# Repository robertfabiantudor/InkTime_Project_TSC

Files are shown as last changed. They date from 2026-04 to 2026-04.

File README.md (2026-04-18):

# InkTime Smartwatch

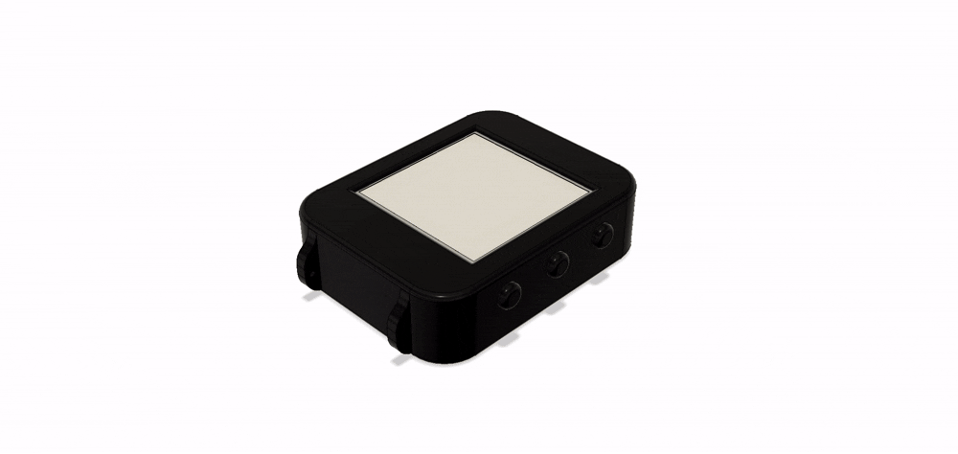
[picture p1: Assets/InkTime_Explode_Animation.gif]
InkTime_Explode_Animation


<br/>
<br/>

## Block Diagram
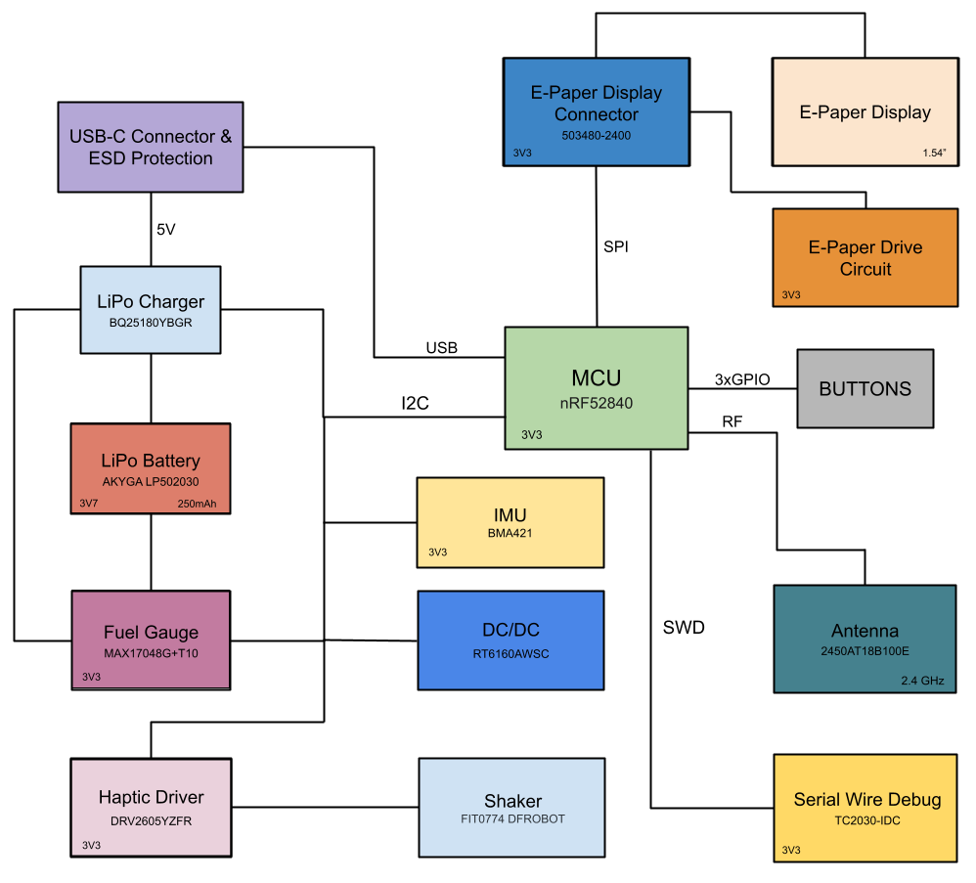
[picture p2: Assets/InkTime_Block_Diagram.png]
InkTime Block Diagram


<br/>
<br/>

## Bill of Materials(BOM)

| Name | Component Type | Part Number | Qty | JLCPCB Part Link | Datasheet Link|
|---|---|---|-----|---|---|
| ANT1 | Antenna | 2450AT18B100E | 1 | [View Part](https://jlcpcb.com/partdetail/JohansonDielectrics-2450AT18B100E/C2917717) | [View Datasheet](https://www.lcsc.com/datasheet/C2917717.pdf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) |
| C1, C2, C17, C18 | Capacitor | GRM0335C1H120JA01D | 4 | [View Part](https://jlcpcb.com/partdetail/MurataElectronics-GRM0335C1H120JA01D/C85890) | [View Datasheet](https://www.lcsc.com/datasheet/C85890.pdf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) |
| C1-EP-DR, C24, C39 | Capacitor | GRM155R60J106ME44D | 3 | [View Part](https://jlcpcb.com/partdetail/MurataElectronics-GRM155R60J106ME44D/C76991) | [View Datasheet](https://www.lcsc.com/datasheet/C76991.pdf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) |
| C2-EP-DR | Capacitor | RVT1E4R7M0405 | 1 | [View Part](https://jlcpcb.com/partdetail/DMBJ-RVT1E4R7M0405_4_7UF25V/C970600) | [View Datasheet](https://www.lcsc.com/datasheet/C2895731.pdf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) |
| C3, C4 | Capacitor | GRM0335C1H1R0BA01D | 2 | [View Part](https://jlcpcb.com/partdetail/MurataElectronics-GRM0335C1H1R0BA01D/C85893) | [View Datasheet](https://www.lcsc.com/datasheet/C85893.pdf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) |
| C5, C7, C8, C12, C19 | Capacitor | GRM033R60J104KE19D | 5 | [View Part](https://jlcpcb.com/partdetail/MurataElectronics-GRM033R60J104KE19D/C76928) | [View Datasheet](https://www.lcsc.com/datasheet/C76928.pdf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) |
| C6, C14, C20, C21, C43 | Capacitor | GRM155R60J475KE96D | 5 | [View Part](https://jlcpcb.com/partdetail/MurataElectronics-GRM155R60J475KE96D/C76995) | [View Datasheet](https://www.lcsc.com/datasheet/C76995.pdf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) |
| C9 | Capacitor | GRM033R71E821KA01D | 1 | [View Part](https://jlcpcb.com/partdetail/197002-GRM033R71E821KA01D/C185597) | [View Datasheet](https://www.lcsc.com/datasheet/C185597.pdf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) |
| C11 | Capacitor | GRM0335C1E101JA01D | 1 | [View Part](https://jlcpcb.com/partdetail/MurataElectronics-GRM0335C1E101JA01D/C76917) | [View Datasheet](https://www.lcsc.com/datasheet/C76917.pdf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) |
| C15 | Capacitor | GRM155R60J105KE19D | 1 | [View Part](https://jlcpcb.com/partdetail/MurataElectronics-GRM155R60J105KE19D/C15684) | [View Datasheet](https://www.lcsc.com/product-detail/C15684.html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) |
| C16, C10, C13, C22 | Capacitor | GRM033R60J473KE19D | 4 | [View Part](https://jlcpcb.com/parts/componentSearch?searchTxt=GRM033R60J473KE19D) | [View Datasheet](https://www.lcsc.com/product-detail/C85925.html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) |
| C25, C33 | Capacitor | GRM155R60J226ME11D | 2 | [View Part](https://jlcpcb.com/partdetail/408393-GRM155R60J226ME11D/C415703) | [View Datasheet](https://www.lcsc.com/datasheet/C415703.pdf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) |
| C23, C27, C29, C30, C31, C32, C34, C37, C38, C42| Capacitor | GRM011R60J152KE01L | 10 | [View Part](https://jlcpcb.com/partdetail/22429554-GRM011R60J152KE01L/C21012218) | [View Datasheet](https://www.lcsc.com/datasheet/C21012218.pdf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) |
| D2, D4, D5  | Schottky Diode | MBR0530 | 3 | [View Part](https://jlcpcb.com/partdetail/onsemi-MBR0530/C232832) | [View Datasheet](https://www.lcsc.com/datasheet/C232832.pdf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) |
| D3 | ESD Protection | USBLC6-2SC6Y | 1 | [View Part](https://jlcpcb.com/partdetail/STMicroelectronics-USBLC62SC6Y/C2969755) | [View Datasheet](https://www.lcsc.com/datasheet/C2969755.pdf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) |
| EPD_C1, EPD_C2, EPD_C6–EPD_C12 | Capacitor | 0201WMJ0100TCE | 9 | [View Part](https://jlcpcb.com/partdetail/25795-0201WMJ0100TCE/C25052) | [View Datasheet](https://www.lcsc.com/datasheet/C25052.pdf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) |
| EPD_C5 | Capacitor | 500R07W104KV4T | 1 | [View Part](https://jlcpcb.com/partdetail/6103901-500R07W104KV4T_0_1uF50v/C5337557) | [View Datasheet](https://www.mouser.com/catalog/specsheets/johanson_joha-s-a0008490164-1.pdf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) |
| IC1 | LiPo Charger | BQ25180YBGR | 1 | [View Part](https://jlcpcb.com/partdetail/TexasInstruments-BQ25180YBGR/C3682423) | [View Datasheet](https://www.ti.com/cn/lit/gpn/bq25180) |
| IC2 | Haptic Driver | DRV2605YZFR | 1 | [View Part](https://jlcpcb.com/partdetail/TexasInstruments-DRV2605YZFR/C81079) | [View Datasheet](https://www.lcsc.com/datasheet/C81079.pdf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) |
| IC3 | IMU | BMA421 | 1 | [View Part](https://jlcpcb.com/partdetail/BoschSensortec-BMA421/C5242966) | [View Datasheet](https://files.pine64.org/doc/datasheet/pinetime/BST-BMA421-FL000.pdf) |
| IC9 | DC/DC Converter | RT6160AWSC | 1 | [View Part](https://jlcpcb.com/partdetail/RichtekTech-RT6160AWSC/C7065276) | [View Datasheet](https://www.lcsc.com/datasheet/C7065276.pdf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) |
| J1 | FPC Connector | 503480-2400 | 1 | [View Part](https://jlcpcb.com/partdetail/MOLEX-5034802400/C122434) | [View Datasheet](https://www.lcsc.com/datasheet/C122434.pdf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) |
| J2 | Debug Connector | TC2030-IDC | 1 | - | [View Datasheet](https://www.tag-connect.com/wp-content/uploads/bsk-pdf-manager/2019/12/TC2030-IDC-Datasheet-Rev-B.pdf) |
| J4 | USB-C Connector | KH-TYPE-C-16P | 1 | [View Part](https://jlcpcb.com/partdetail/Shenzhen_KinghelmElec-KH_TYPE_C16P/C709357) | [View Datasheet](https://www.lcsc.com/datasheet/C709357.pdf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) |
| L1 | Inductor | LQG15HS3N9S02D | 1 | [View Part](https://jlcpcb.com/partdetail/MurataElectronics-LQG15HS3N9S02D/C77109) | [View Datasheet](https://www.lcsc.com/datasheet/C77109.pdf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) |
| L2 | Inductor | LQW15DN100M00D | 1 | [View Part](https://jlcpcb.com/partdetail/MurataElectronics-LQW15DN100M00D/C910650) | [View Datasheet](https://www.lcsc.com/datasheet/C910650.pdf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) |
| L3 | Inductor | LQG15HS15NJ02D| 1 | [View Part](https://jlcpcb.com/partdetail/MurataElectronics-LQG15HS15NJ02D/C86059) | [View Datasheet](https://www.lcsc.com/datasheet/C86059.pdf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) |
| L5 | Inductor | LQG15HS27NJ02D | 1 | [View Part](https://jlcpcb.com/partdetail/MurataElectronics-LQG15HS27NJ02D/C12669) | [View Datasheet](https://www.lcsc.com/datasheet/C12669.pdf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) |
| L7 | Inductor | LQW15CNR47K10D| 1 | [View Part](https://jlcpcb.com/partdetail/MurataElectronics-LQW15CNR47K10D/C913544) | [View Datasheet](https://www.lcsc.com/datasheet/C913544.pdf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) |
| Q1 | P-Channel MOSFET | DMG2305UX-7 | 1 | [View Part](https://jlcpcb.com/partdetail/DiodesIncorporated-DMG2305UX7/C150470) | [View Datasheet](https://www.lcsc.com/datasheet/C150470.pdf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) |
| Q3 | N-Channel MOSFET | SI1308EDL-T1-GE3 | 1 | [View Part](https://jlcpcb.com/partdetail/VishayIntertech-SI1308EDL_T1GE3/C469327) | [View Datasheet](https://www.lcsc.com/datasheet/C469327.pdf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) |
| R_PWR_EPD, R2_EP_DR, R9 | Resistor | CPF0201D10KC1 | 3 | [View Part](https://jlcpcb.com/partdetail/TEConnectivity-CPF0201D10KC1/C4187156) | [View Datasheet](https://www.lcsc.com/datasheet/C4187156.pdf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) |
| R_TYPE_SEL | Resistor | RC0201FR-072R2L | 1 | [View Part](https://jlcpcb.com/partdetail/YAGEO-RC0201FR072R2L/C138154) | [View Datasheet](https://www.lcsc.com/datasheet/C138154.pdf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) |
| R1_EP_DR | Resistor | 25121WF470LT4E | 1 | [View Part](https://jlcpcb.com/partdetail/21809-25121WF470LT4E/C21097) | [View Datasheet](https://www.lcsc.com/datasheet/C21097.pdf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) |
| R1_USB1, R2_USB | Resistor | RC0201JR-075K1L | 2 | [View Part](https://jlcpcb.com/partdetail/YAGEO-RC0201JR075K1L/C163490) | [View Datasheet](https://www.lcsc.com/datasheet/C163490.pdf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) |
| R2, R3, R4 | Resistor | RC0201FR-070RL | 3 | [View Part](https://jlcpcb.com/partdetail/YAGEO-RC0201FR070RL/C106227) | [View Datasheet](https://www.lcsc.com/datasheet/C106227.pdf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) |
| R5, R7, R8 | Resistor | RC0201FR-0710KL | 3 | [View Part](https://jlcpcb.com/partdetail/YAGEO-RC0201FR0710KL/C106225) | [View Datasheet](https://www.lcsc.com/product-detail/C106225.html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) |
| R17, R18 | Resistor | AC0201FR-073K3L | 2 | [View Part](https://jlcpcb.com/partdetail/YAGEO-AC0201FR073K3L/C226534) | [View Datasheet](https://www.lcsc.com/datasheet/C226534.pdf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) |
| SW_DN, SW_ENT, SW_UP | Button | EVP-AKE31A | 3 | [View Part](https://jlcpcb.com/partdetail/PANASONIC-EVPAKE31A/C569760) | [View Datasheet](https://www.lcsc.com/datasheet/C569760.pdf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) |
| U1 | MCU | NRF52840-QIAA-R | 1 | [View Part](https://jlcpcb.com/partdetail/NordicSemicon-NRF52840_QIAAR/C190794) | [View Datasheet](https://www.lcsc.com/datasheet/C190794.pdf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) |
| U3 | Fuel Gauge | MAX17048G+T10 | 1 | [View Part](https://jlcpcb.com/partdetail/2777647-MAX17048GT10/C2682616) | [View Datasheet](https://www.lcsc.com/datasheet/C2682616.pdf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) |
| X1 | Crystal | X201232768KJD2SI | 1 | [View Part](https://jlcpcb.com/partdetail/357115-X201232768KJD2SI/C383843) | [View Datasheet](https://www.lcsc.com/datasheet/C383843.pdf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) |
| X2 | Crystal | X322532MOB4SI | 1 | [View Part](https://jlcpcb.com/partdetail/YXC_CrystalOscillators-X322532MOB4SI/C9009) | [View Datasheet](https://www.lcsc.com/datasheet/C9009.pdf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) |

<br/>
<br/>

## Hardware Functionality
### Overview
The system is built around the **nRF52840 microcontroller**, which controls all peripherals and manages communication between them. The design is centered on low power consumption and efficient interaction between modules.

<br/>

### Power Management
- Power is supplied through the **USB-C connector**, protected by an **ESD protection circuit**.  
- The input voltage is managed by the **LiPo charger**, which charges the battery and provides power to the system.
- A **DC/DC converter** generates a stable voltage of **3.3V** used by all components, ensuring consistent operation regardless of battery level.
- The **Fuel Gauge** monitors battery status and provides charge information to the MCU.

<br/>

### Communication Interfaces
- **I2C Bus**
  - Used by: IMU, Fuel Gauge, Haptic Driver, LiPo Charger  
  - Provides communication over shared **SDA** and **SCL** lines  
  - Allows multiple low-speed peripherals to be connected on the same bus  
  - Operates at standard or fast mode speeds, sufficient for sensor data and status monitoring  

- **SPI Bus**
  - Used by: E-Paper Display  
  - Enables fast data transfer required for updating the display  
  - Uses dedicated lines for clock and data, allowing higher throughput compared to I2C  

- **USB**
  - Used for power input and battery charging  
  - Can also be used for firmware upload or data communication if needed  

- **SWD**
  - Used for programming and debugging  
  - Provides direct access to the microcontroller for firmware flashing and real-time debugging

<br/>

### Display
- The **E-Paper display** is connected via an FPC connector and controlled through the SPI interface.  
- A dedicated **E-Paper driver circuit** manages the display operation.
- E-paper technology only consumes power while refreshing the image, which makes it well suited for low-power applications. To take full advantage of this, the display is powered through a controlled power switch, allowing it to be completely turned off when not actively used. This approach significantly reduces overall power consumption and extends battery life, especially in scenarios where the display content does not need to be updated frequently.

<br/>

### Sensors and Feedback Systems
- **IMU**  
  - The IMU is an accelerometer that is used for motion detection and activity tracking. 
  - It detects movement, orientation, steps and it can generate interrupts so the microcontroller only wakes up when needed, improving power efficiency.

- **Haptic Driver & Shaker**  
  - The haptic driver controls a vibration motor that provides user feedback. 
  - It is configured through I2C and can trigger predefined vibration patterns for notifications.

<br/>

### User Inputs
- **Buttons**  
  - The buttons are connected to GPIO pins and are used to detect user actions. 
  - They can trigger interrupts, allowing the system to wake from low-power states and respond quickly.

<br/>

### Wireless Connectivity
- **Antenna**  
  - The antenna is connected to the microcontroller's RF pin and is used for Low Energy communication via Bluetooth.
  - It enables wireless data exchange with external devices such as smartphones.

<br/>

### Debug Interface
- **Serial Wire Debug (SWD)**  
  - The SWD interface is used for programming and debugging the system during development. 
  - It provides direct access to the microcontroller for firmware upload and troubleshooting.

<br/>
<br/>

## MCU Pin Assignment
| Pin Names | Purpose | Target Component |
|---|---|---|
| DEC1-DEC6, DEC3V3 | Decoupling pins for stable internal power | External Decoupling Capacitors|
| P0.00/XL1, P0.01/XL2 | Used to connect external 32.768 kHz Crystal Oscillator (X2) | X2 Crystal Oscillator |
| P0.26 | Unused | Not connected |
| P0.27 | Unused | Not connected |
| P0.04/AIN2 | Unused | Not connected |
| P0.05/AIN3 | Chip Select (CS) - Enables communication with the display controller | E-Paper Display |
| P0.06, P0.07 | SDA & SCL - Used as shared I2C communication lines for connected devices| IMU, Fuel Gauge, Haptic Driver, LiPo Charger |
| P0.08, P1.08 | Used to receive interrupt signals from the accelerometer | IMU |
| P1.09 | Unused | Not connected |
| P0.11 | PMIC Interrupt - Indicates charging or power events | LiPo Charger |
| P0.12 | Haptic Enable: Sends a signal to activate the vibration motor | Haptic Driver |
| VDD, VDDH | Supply power to the system | DC/DC Converter |
| DCCH | Unused | Not connected |
| VBUS | Detects when USB power is present | USB-C Connector |
| D-, D+ | Carry USB data signals for communication | USB-C Connector |
| P0.13, P0.14, P1.02  | Connected to physical buttons for user input | Buttons |
| P0.15, P0.16, P0.17  | Used to control the display by selecting data or commands, resetting it when needed and checking if it is busy during updates | E-Paper Display |
| P0.18/RESET | Hardware reset signal | Reset Circuit |
| P0.19 | Unused | Not connected |
| P0.20 | Unused | Not connected |
| P0.21 | Unused | Not connected |
| P0.22 | Unused | Not connected |
| P0.23 | Unused | Not connected |
| P0.24 | Unused | Not connected |
| P0.25 | Unused | Not connected |
| P1.00 | Used for Serial Wire Output to send debug and trace data during development | Debug Interface (SWO) |
| VSS, VSS_PAD, VSS_PA | Ground connections | Main Ground Plane |
| XC1, XC2 | Provide the main high-frequency clock for the system and radio | X1 Crystal Oscillator |
| ANT | Connects the RF signal to the antenna | Antenna |
| P0.10/NFC2 | Fuel Gauge Alert - Signals low battery | Fuel Gauge |
| P0.09/NFC1 | Unused | Not connected |
| P1.07 | Unused | Not connected |
| P1.06 | Unused | Not connected |
| P1.05 | Unused | Not connected |
| P1.04 | Unused | Not connected |
| P1.03 | Unused | Not connected |
| P1.01 | Controls the power to the e-paper display by turning it on or off to save battery | E-Paper Power Switch (Q1 MOSFET) |
| SWDIO, SWDCLK | Used for programming and debugging through the SWD interface | Debug Port |
| DCC | Output from internal voltage regulators | LC Filter Circuit |
| P0.31/AIN7 | Unused | Not connected |
| P0.30/AIN6 | Unused | Not connected |
| P0.29/AIN5 | Unused | Not connected |
| P0.28/AIN4 | Unused | Not connected |
| P0.02/AIN0 | SPI Clock (SCK) - Synchronizes data sent to the display | E-Paper Display |
| P0.03/AIN1 | SPI Data Line (MOSI) - Sends data to the display | E-Paper Display |
| P1.15 | Unused | Not connected |
| P1.14 | Unused | Not connected |
| P1.13 | Unused | Not connected |
| P1.12 | Unused | Not connected |
| P1.11 | Unused | Not connected |
| P1.10 | Unused | Not connected |

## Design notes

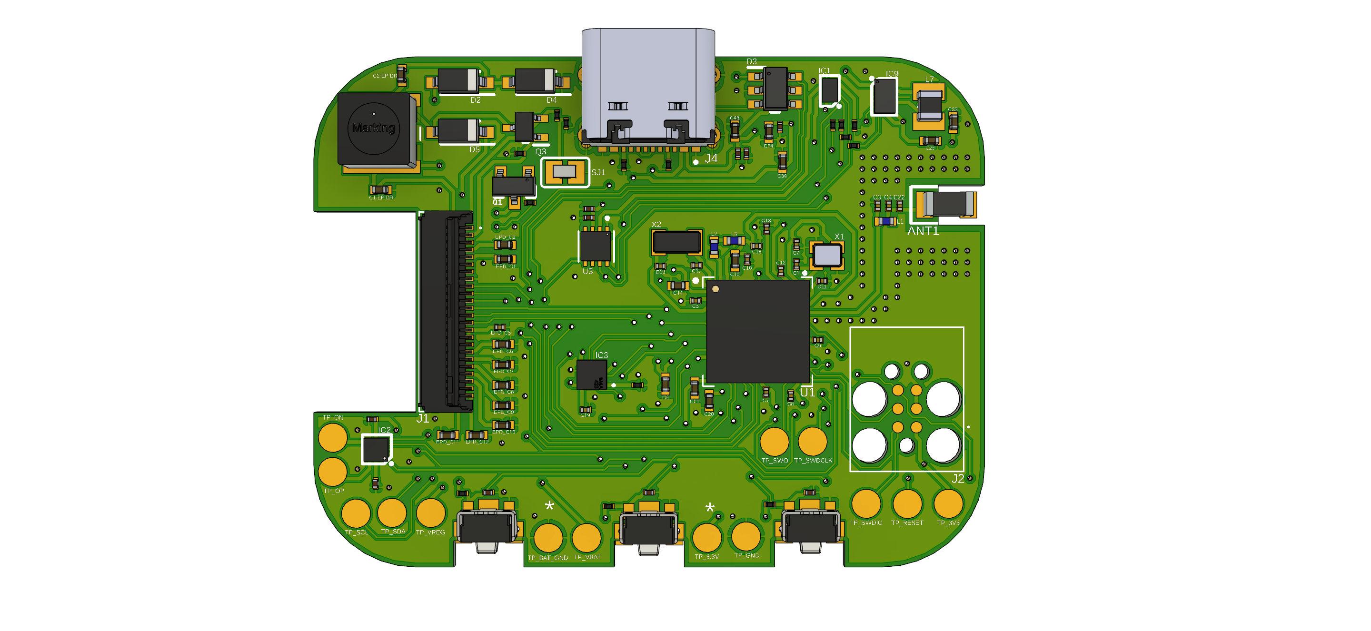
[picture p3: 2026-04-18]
Images/InkTime_3D_PCB_Front_View.png

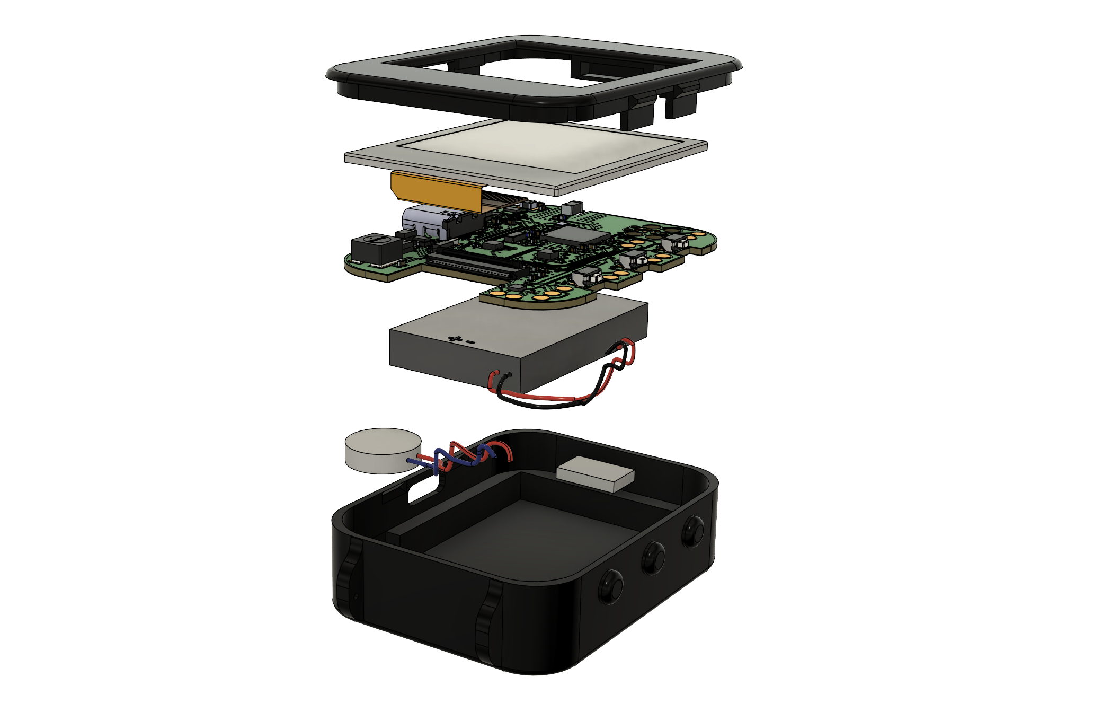
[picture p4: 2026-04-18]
Images/InkTime_Exploded_View.png

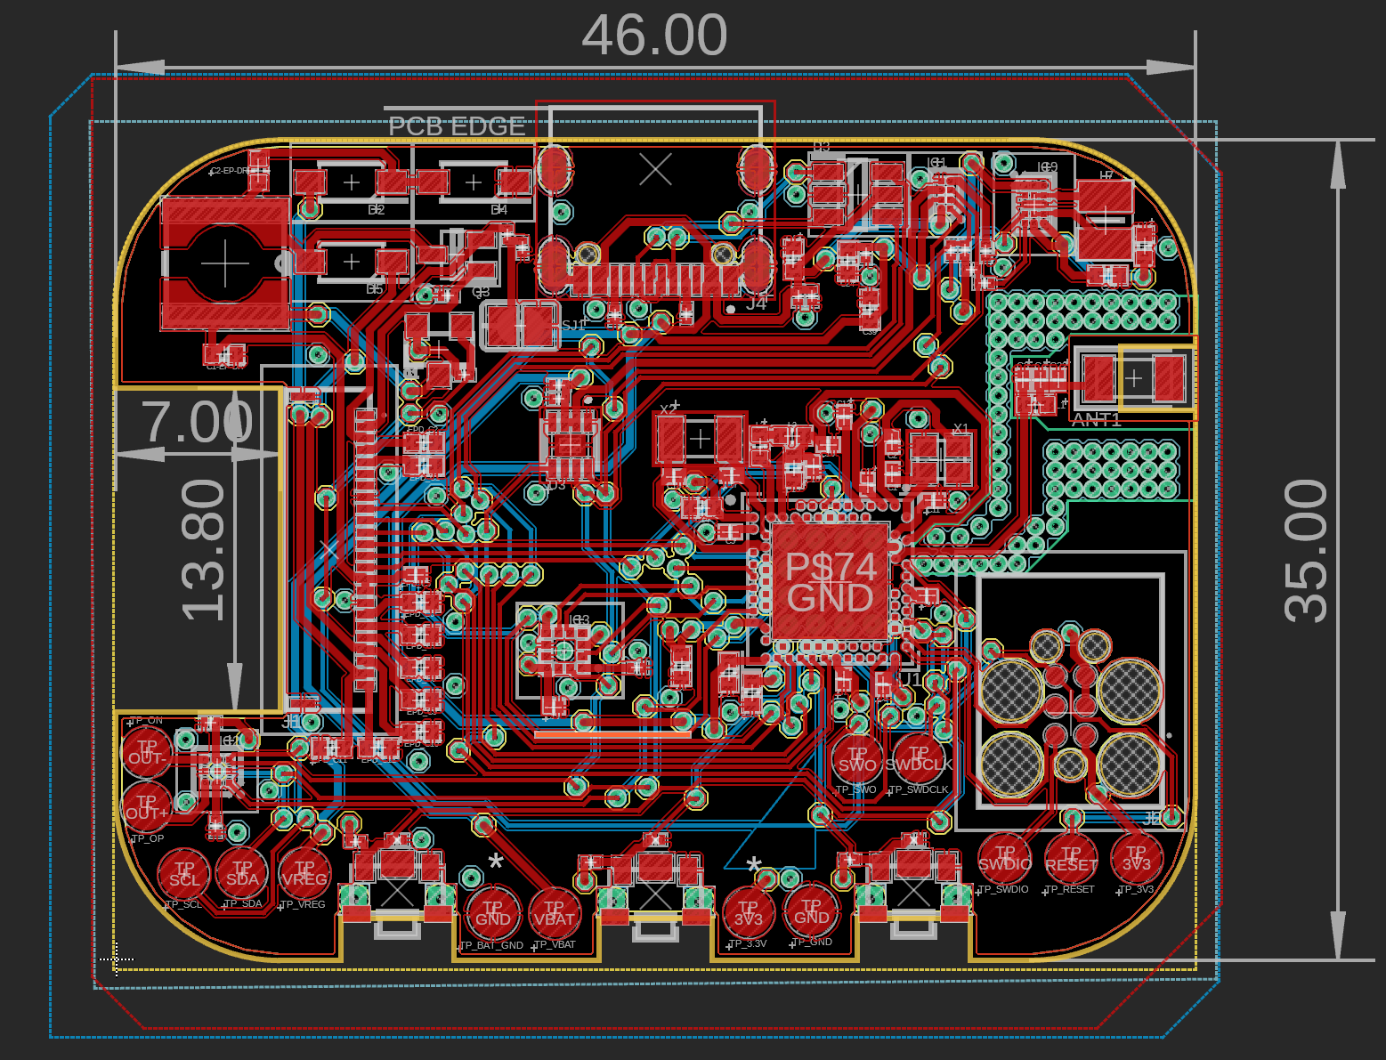
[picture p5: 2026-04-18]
Images/InkTime_2D_PCB.png

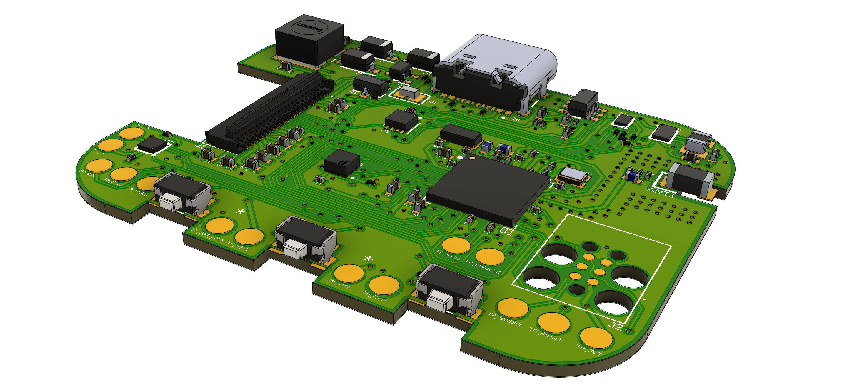
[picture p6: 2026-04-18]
Images/InkTime_3D_PCB_Angled_View.png

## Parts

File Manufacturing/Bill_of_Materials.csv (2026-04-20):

Qty | Value | Device | Package | Parts | Description | ARROW_PART_NUMBER | ARROW_PRICE-STOCK | AVAILABILITY | CHECK_PRICES | COPYRIGHT | DESCRIPTION | DIGI-KEY_PART_NUMBER_1 | DIGI-KEY_PART_NUMBER_2 | DIGI-KEY_PART_NUMBER_3 | HEIGHT | JLCPCB | MANUFACTURER_NAME | MANUFACTURER_PART_NUMBER | MF | MFR_NAME | MOUSER_PART_NUMBER | MOUSER_PRICE-STOCK | MP | PACKAGE | POPULARITY | PRICE | PROD_ID | PURCHASE-URL | SNAPEDA_LINK | TP_SIGNAL_NAME | VALUE
1 |  | ESP32_C6_LIBRARY_7_JUMPER_SJ | ESP32_C6_LIBRARY_7_JUMPER_SJ | SJ1 | SMD solder JUMPER |  |  |  |  |  |  |  |  |  |  |  |  |  |  |  |  |  |  |  | 3
3 | 0 | CPF0201D7K68C1_CPF0201D7K68C1 | CPF0201D7K68C1_0201 | R2, R3, R4 | 7.68k 0201 Thin Film Surface Mount Fixed Resistor +/-0.5% 0.031W CPF0201D7K68C1
4 | 0.1uF | GRM011R60J152KE01L_1_GRM011R60J152KE01L | GRM011R60J152KE01L_1_0201 | C23, C27, C34, C42 | Check availability
1 | 0.1uF/50V | NORDIC_NRF_3_CAPACITOR_0201_L | NORDIC_NRF_3_RESC0201_L | EPD_C5 | Generic chip capacitor
1 | 0.47 | CPF0201D7K68C1_CPF0201D7K68C1 | CPF0201D7K68C1_0201 | R1_EP_DR | 7.68k 0201 Thin Film Surface Mount Fixed Resistor +/-0.5% 0.031W CPF0201D7K68C1
1 | 1.0µF | NORDIC_NRF_3_CAPACITOR_0402_L | NORDIC_NRF_3_RESC0402_L | C15 | Generic chip capacitor
5 | 100nF | NORDIC_NRF_3_CAPACITOR_0201_L | NORDIC_NRF_3_RESC0201_L | C5, C7, C8, C12, C19 | Generic chip capacitor
1 | 100pF | NORDIC_NRF_3_CAPACITOR_0201_L | NORDIC_NRF_3_RESC0201_L | C11 | Generic chip capacitor
3 | 10K | CPF0201D7K68C1_CPF0201D7K68C1 | CPF0201D7K68C1_0201 | R2_EP_DR, R9, R_PWR_EPD | 7.68k 0201 Thin Film Surface Mount Fixed Resistor +/-0.5% 0.031W CPF0201D7K68C1
3 | 10k | CPF0201D7K68C1_CPF0201D7K68C1 | CPF0201D7K68C1_0201 | R5, R7, R8 | 7.68k 0201 Thin Film Surface Mount Fixed Resistor +/-0.5% 0.031W CPF0201D7K68C1
3 | 10uF | NORDIC_NRF_3_CAPACITOR_0402_L | NORDIC_NRF_3_RESC0402_L | C1-EP-DR, C24, C39 | Generic chip capacitor
1 | 10µH | NORDIC_NRF_2_INDUCTOR_0402_L | NORDIC_NRF_2_RESC0402_L | L2 | Generic chip inductor
4 | 12pF | NORDIC_NRF_3_CAPACITOR_0201_L | NORDIC_NRF_3_RESC0201_L | C1, C2, C17, C18 | Generic chip capacitor
1 | 15nH | NORDIC_NRF_2_INDUCTOR_0402_L | NORDIC_NRF_2_RESC0402_L | L3 | Generic chip inductor
2 | 1pF | NORDIC_NRF_3_CAPACITOR_0201_L | NORDIC_NRF_3_RESC0201_L | C3, C4 | Generic chip capacitor
6 | 1uF | GRM011R60J152KE01L_1_GRM011R60J152KE01L | GRM011R60J152KE01L_1_0201 | C29, C30, C31, C32, C37, C38 | Check availability
9 | 1uF/50V | NORDIC_NRF_3_CAPACITOR_0402_L | NORDIC_NRF_3_RESC0402_L | EPD_C1, EPD_C2, EPD_C6, EPD_C7, EPD_C8, EPD_C9, EPD_C10, EPD_C11, EPD_C12 | Generic chip capacitor
1 | 2.2 | CPF0201D7K68C1_CPF0201D7K68C1 | CPF0201D7K68C1_0201 | R_TYPE_SEL | 7.68k 0201 Thin Film Surface Mount Fixed Resistor +/-0.5% 0.031W CPF0201D7K68C1
3 | 2025-10-22_07-23-44_LIBRARY_EVP-AKE31ASW_EVP-AKE31A_PAN | 2025-10-22_07-23-44_LIBRARY_EVP-AKE31ASW_EVP-AKE31A_PAN | 2025-10-22_07-23-44_LIBRARY_SW_EVP-AKE31A_PAN | SW_DN, SW_ENT, SW_UP |  |  |  |  |  | Copyright (C) 2025 Ultra Librarian. All rights reserved. |  | P123437TR-ND | P123437CT-ND | P123437DKR-ND |  |  | Panasonic | EVP-AKE31A
1 | 20V/4.2A/52mO/1.4W | ESP32_C6_LIBRARY_4_ESP32_WROVER_SPARKFUN-DISCRETESEMI_MOSFET_PCH-DMG2305UX-7 | ESP32_C6_LIBRARY_4_ESP32_C6_LIBRARY_4_ESP32_C6_LIBRARY_4_ESP32_C6_LIBRARY_4_ESP32_WROVER_SPARKFUN-DISCRETESEMI_SOT23-3 | Q1 | P-channel MOSFETs |  |  |  |  |  |  |  |  |  |  |  |  |  |  |  |  |  |  |  |  |  | TRAN-14388 |  |  |  | 20V/4.2A/52mO/1.4W
2 | 22uF | NORDIC_NRF_3_CAPACITOR_0402_L | NORDIC_NRF_3_RESC0402_L | C25, C33 | Generic chip capacitor
1 | 2450AT18B100E | 2450AT18B100E_2450AT18B100E | 2450AT18B100E_ANTC3216X140N | ANT1 | Antennas 2.45GHz ANTENNA | 2450AT18B100E | https://www.arrow.com/en/products/2450at18b100e/johanson-dielectrics?utm_currency=USD&region=nac |  |  |  | Antennas 2.45GHz ANTENNA |  |  |  | 1.4mm |  | JOHANSON TECHNOLOGY | 2450AT18B100E |  |  | 609-2450AT18B100E | https://www.mouser.co.uk/ProductDetail/Johanson-Technology/2450AT18B100E?qs=yCnrNFeXz%252Bh5MFsFIXGZGA%3D%3D
1 | 3.9nH | NORDIC_NRF_2_INDUCTOR_0402_L | NORDIC_NRF_2_RESC0402_L | L1 | Generic chip inductor
1 | 32.768kHz | NORDIC_NRF_1_XTAL_32KHZ | NORDIC_NRF_1_XTAL_3215_N | X2
1 | 32MHz | NORDIC_NRF_XTAL_32MHZ | NORDIC_NRF_BT-XTAL_2016_N | X1
2 | 3K3 | CPF0201D7K68C1_CPF0201D7K68C1 | CPF0201D7K68C1_0201 | R17, R18 | 7.68k 0201 Thin Film Surface Mount Fixed Resistor +/-0.5% 0.031W CPF0201D7K68C1
1 | 4.7uF | NORDIC_NRF_3_CAPACITOR_0402_L | NORDIC_NRF_3_RESC0402_L | C43 | Generic chip capacitor
1 | 4.7uF/25V | NORDIC_NRF_3_CAPACITOR_0402_L | NORDIC_NRF_3_RESC0402_L | C2-EP-DR | Generic chip capacitor
4 | 4.7µF | NORDIC_NRF_3_CAPACITOR_0402_L | NORDIC_NRF_3_RESC0402_L | C6, C14, C20, C21 | Generic chip capacitor
1 | 47nF | NORDIC_NRF_3_CAPACITOR_0201_L | NORDIC_NRF_3_RESC0201_L | C16 | Generic chip capacitor
1 | 503480-2400 | 503480-2400_503480-2400 | 503480-2400_5034802400 | J1 | FFC & FPC Connectors 0.5mm FPC RA SMT Dual Contact 24Ckt |  |  |  |  |  | FFC & FPC Connectors 0.5mm FPC RA SMT Dual Contact 24Ckt |  |  |  | 1.87mm |  | Molex | 503480-2400 |  |  | 538-503480-2400 | https://www.mouser.co.uk/ProductDetail/Molex/503480-2400?qs=OAhjpuo3Vu7efIoxFh9AOw%3D%3D
2 | 5K1 | CPF0201D7K68C1_CPF0201D7K68C1 | CPF0201D7K68C1_0201 | R1_USB1, R2_USB | 7.68k 0201 Thin Film Surface Mount Fixed Resistor +/-0.5% 0.031W CPF0201D7K68C1
1 | 68uH | ESP32_C6_LIBRARY_2_744043680IND_4828-WE-TPC_WRE | ESP32_C6_LIBRARY_2_IND_4828-WE-TPC_WRE | L5 |  |  |  |  |  | Copyright (C) 2024 Ultra Librarian. All rights reserved. |  |  |  |  |  |  |  | 744043680 |  | Wurth Electronics
1 | 820pF | NORDIC_NRF_3_CAPACITOR_0201_L | NORDIC_NRF_3_RESC0201_L | C9 | Generic chip capacitor
1 | BMA421 | BMA423_BMA423 | BMA423_BMA423 | IC3 | Accelerometers Triaxial low-g 12bit Acceleration Sensor | BMA423 | https://www.arrow.com/en/products/bma423/bosch |  |  |  | Accelerometers Triaxial low-g 12bit Acceleration Sensor |  |  |  | 1mm |  | BOSCH | BMA423 |  |  | 262-BMA423 | https://www.mouser.co.uk/ProductDetail/Bosch-Sensortec/BMA423?qs=HXFqYaX1Q2xC%252BSgeGoX3mg%3D%3D
1 | BQ25180YBGR | BQ25180YBGR_BQ25180YBGR | BQ25180YBGR_BGA8C40P2X4_100X155X50 | IC1 | Charger IC Lithium Ion/Polymer, Lithium Iron Phosphate 8-DSBGA (1.6x1.1) | BQ25180YBGR | https://www.arrow.com/en/products/bq25180ybgr/texas-instruments?utm_currency=USD&region=nac |  |  |  | Charger IC Lithium Ion/Polymer | Lithium Iron Phosphate 8-DSBGA (1.6x1.1) |  |  |  | 0.5mm |  | Texas Instruments | BQ25180YBGR |  |  | 595-BQ25180YBGR | https://www.mouser.co.uk/ProductDetail/Texas-Instruments/BQ25180YBGR?qs=doiCPypUmgEWjAK%252BJAX6Tw%3D%3D
1 | DRV2605YZFR | DRV2605YZFR_DRV2605YZFR | DRV2605YZFR_BGA9C50P3X3_144X144X62 | IC2 | Haptic Driver for ERM/LRA with Built-In Library and Smart Loop Architecture | DRV2605YZFR | https://www.arrow.com/en/products/drv2605yzfr/texas-instruments?region=nac |  |  |  | Haptic Driver for ERM/LRA with Built-In Library and Smart Loop Architecture |  |  |  | 0.625mm |  | Texas Instruments | DRV2605YZFR
1 | FTC252012SR47MBCA | MLP2016SR47MT0S1_FTC252012SR47MBCA | MLP2016SR47MT0S1_INDC2016X100N | L7 | SMD / SMT Inductors (Coils), L=0.47?H, L x W x T : |  |  |  |  |  | SMD / SMT Inductors (Coils) | L=0.47?H | L x W x T : |  |  |  | 1mm | https://jlcpcb.com/partdetail/6763488-FTC252012SR47MBCA/C5832368 | TDK | FTC252012SR47MBCA
14 | HECTOR_WATCH_1_TPTP20R | HECTOR_WATCH_1_TPTP20R | HECTOR_WATCH_1_TP20R | TP_3.3V, TP_3V3, TP_BAT_GND, TP_GND, TP_ON, TP_OP, TP_RESET, TP_SCL, TP_SDA, TP_SWDCLK, TP_SWDIO, TP_SWO, TP_VBAT, TP_VREG | Test pad |  |  |  |  |  |  |  |  |  |  |  |  |  |  |  |  |  |  |  | 2
1 | KH-TYPE-C-16P | KH-TYPE-C-16P_KH-TYPE-C-16P | KH-TYPE-C-16P_KINGHELM_KH-TYPE-C-16P | J4 | Check availability |  |  | Not in stock | https://www.snapeda.com/parts/KH-TYPE-C-16P/Kinghelm/view-part/?ref=eda |  |  |  |  |  |  |  |  |  | kinghelm |  |  |  | KH-TYPE-C-16P | None |  | None |  |  | https://www.snapeda.com/parts/KH-TYPE-C-16P/Kinghelm/view-part/?ref=snap
1 | MAX17048G+T10 | ESP32_C6_LIBRARY_MAX17048G+T10 | ESP32_C6_LIBRARY_SON50P200X200X80-9N | U3 | Check availability |  |  | In Stock | https://www.snapeda.com/parts/MAX17048G+T10/Analog+Devices/view-part/?ref=eda |  | 3µA 1-Cell/2-Cell Fuel Gauge with ModelGauge |  |  |  |  |  |  |  | Analog Devices |  |  |  | MAX17048G+T10 | TDFN-8 Maxim |  | None |  | https://www.snapeda.com/api/url_track_click_mouser/?unipart_id=329239&manufacturer=Analog Devices&part_name=MAX17048G+T10&search_term=None | https://www.snapeda.com/parts/MAX17048G+T10/Analog+Devices/view-part/?ref=snap
3 | MBR0530 | ESP32_C6_LIBRARY_5_MBR0530 | ESP32_C6_LIBRARY_5_SOD3716X135N | D4, D5 | ON SEMICONDUCTOR - MBR0530 - DIODE, SCHOTTKY, 0.5A, 30V, SOD-123 |  |  | In Stock | https://www.snapeda.com/parts/MBR0530/Onsemi/view-part/?ref=eda |  | Diode Schottky 30 V 500mA Surface Mount SOD-123 |  |  |  |  |  |  |  | ON Semiconductor |  |  |  | MBR0530 | SOD-123-2 ON Semiconductor |  | None |  | https://www.snapeda.com/api/url_track_click_mouser/?unipart_id=179458&manufacturer=ON Semiconductor&part_name=MBR0530&search_term=None | https://www.snapeda.com/parts/MBR0530/Onsemi/view-part/?ref=snap
3 | N.C. | NORDIC_NRF_3_CAPACITOR_0201_L | NORDIC_NRF_3_RESC0201_L | C10, C13, C22 | Generic chip capacitor
1 | NRF52840_QF | NORDIC_NRF_4_NRF52840_QF | NORDIC_NRF_4_AQFN50P700X700X85_HS-74N | U1 | nRF52840
1 | RT6160AWSC | RT6160AWSC_RT6160AWSC | RT6160AWSC_BGA15C40P3X5_140X230X60 | IC9 | Buck-Boost Regulator Positive Output Step-Up/Step-Down I2C DC-DC Controller IC 15-WL-CSP (BSC) (1.4x2.3) |  |  |  |  |  | Buck-Boost Regulator Positive Output Step-Up/Step-Down I2C DC-DC Controller IC 15-WL-CSP (BSC) (1.4x2.3) |  |  |  | 0.6mm |  | RICHTEK | RT6160AWSC |  |  | 835-RT6160AWSC | https://www.mouser.co.uk/ProductDetail/Richtek/RT6160AWSC?qs=amGC7iS6iy%2FLd9PSoixZXQ%3D%3D
1 | SI1308EDL-T1-GE3 | ESP32_C6_LIBRARY_6_SI1308EDL-T1-GE3 | ESP32_C6_LIBRARY_6_SOT65P210X110-3N | Q3 | MOSFET N-Ch 30V 1.5A TrenchFET SC70 Vishay Si1308EDL-T1-GE3 N-channel MOSFET Transistor, 1.5 A, 30 V, 3-Pin SC-70 |  |  | In Stock | https://www.snapeda.com/parts/SI1308EDL-T1-GE3/Vishay+Siliconix/view-part/?ref=eda |  | Si1308EDL-T1-GE3 N-channel MOSFET Transistor | 1.5 A | 30 V | 3-Pin SC-70 | Siliconix / Vishay SI1308EDL-T1-GE3 |  |  |  |  |  |  |  | Vishay Siliconix |  |  |  | SI1308EDL-T1-GE3 | SOT-323 Vishay Semiconductor |  | None |  | https://www.snapeda.com/api/url_track_click_mouser/?unipart_id=274603&manufacturer=Vishay Siliconix&part_name=SI1308EDL-T1-GE3&search_term=None
1 | TC2030-IDC_TC2030-IDC | TC2030-IDC_TC2030-IDC | TC2030-IDC_TC2030IDC | J2 | CABLE ADAPTER 6 POS |  |  |  |  |  | CABLE ADAPTER 6 POS |  |  |  | 19mm |  | Tag Connect | TC2030-IDC
1 | USBLC6-2SC6Y | ESP32_C6_LIBRARY_3_USBLC6-2SC6Y | ESP32_C6_LIBRARY_3_SOT95P280X145-6N | D3 | Low Cap. ESD Protection Auto SOT-23-6 STMicroelectronics USBLC6-2SC6Y, Dual Uni-Directional TVS Diode Array, 6-Pin SOT-23 |  |  | In Stock | https://www.snapeda.com/parts/USBLC6-2SC6Y/STMicroelectronics/view-part/?ref=eda |  | 17V Clamp 5A (8/20µs) Ipp Tvs Diode Surface Mount SOT-23-6 |  |  |  |  |  |  |  | STMicroelectronics |  |  |  | USBLC6-2SC6Y | SOT-23-6 STMicroelectronics |  | None |  |  | https://www.snapeda.com/parts/USBLC6-2SC6Y/STMicroelectronics/view-part/?ref=snap

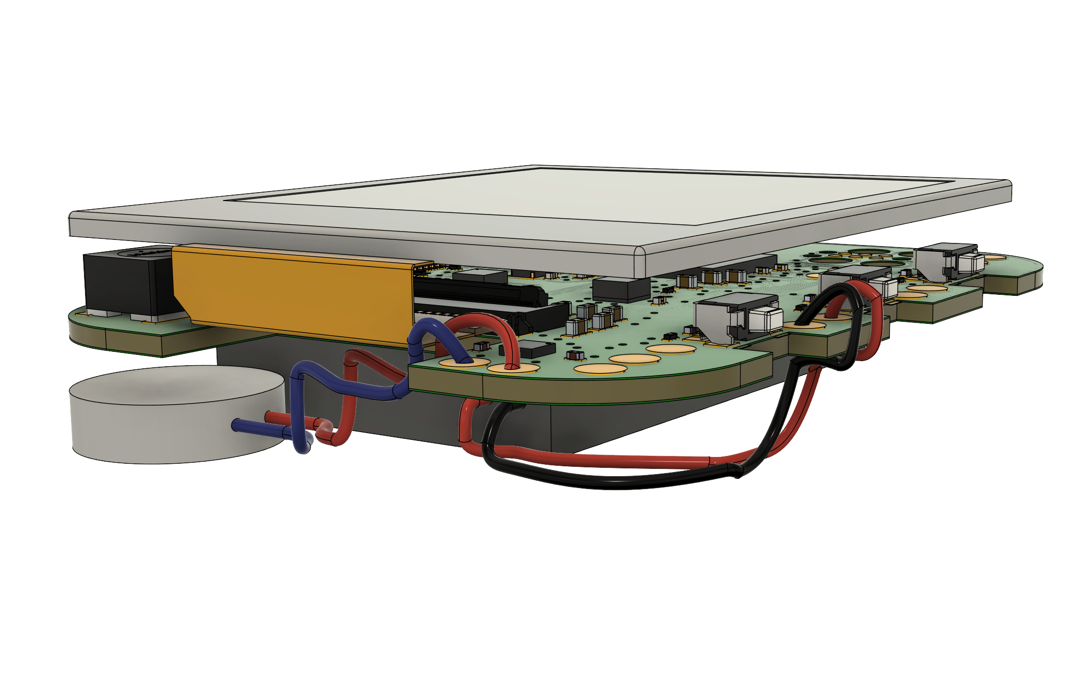
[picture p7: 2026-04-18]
Images/InkTime_Board_With_Custom_Components.png

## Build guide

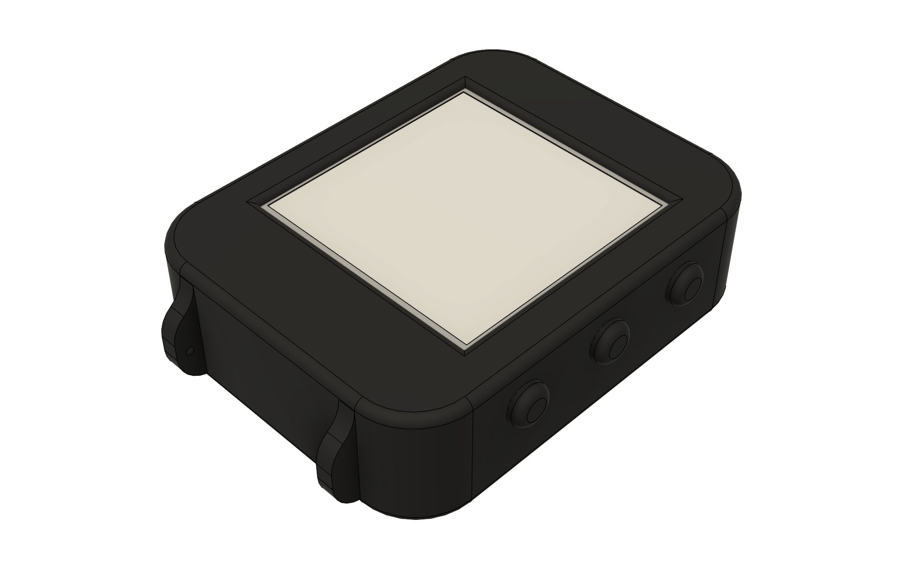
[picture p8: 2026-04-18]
Images/InkTime_Assembled.png

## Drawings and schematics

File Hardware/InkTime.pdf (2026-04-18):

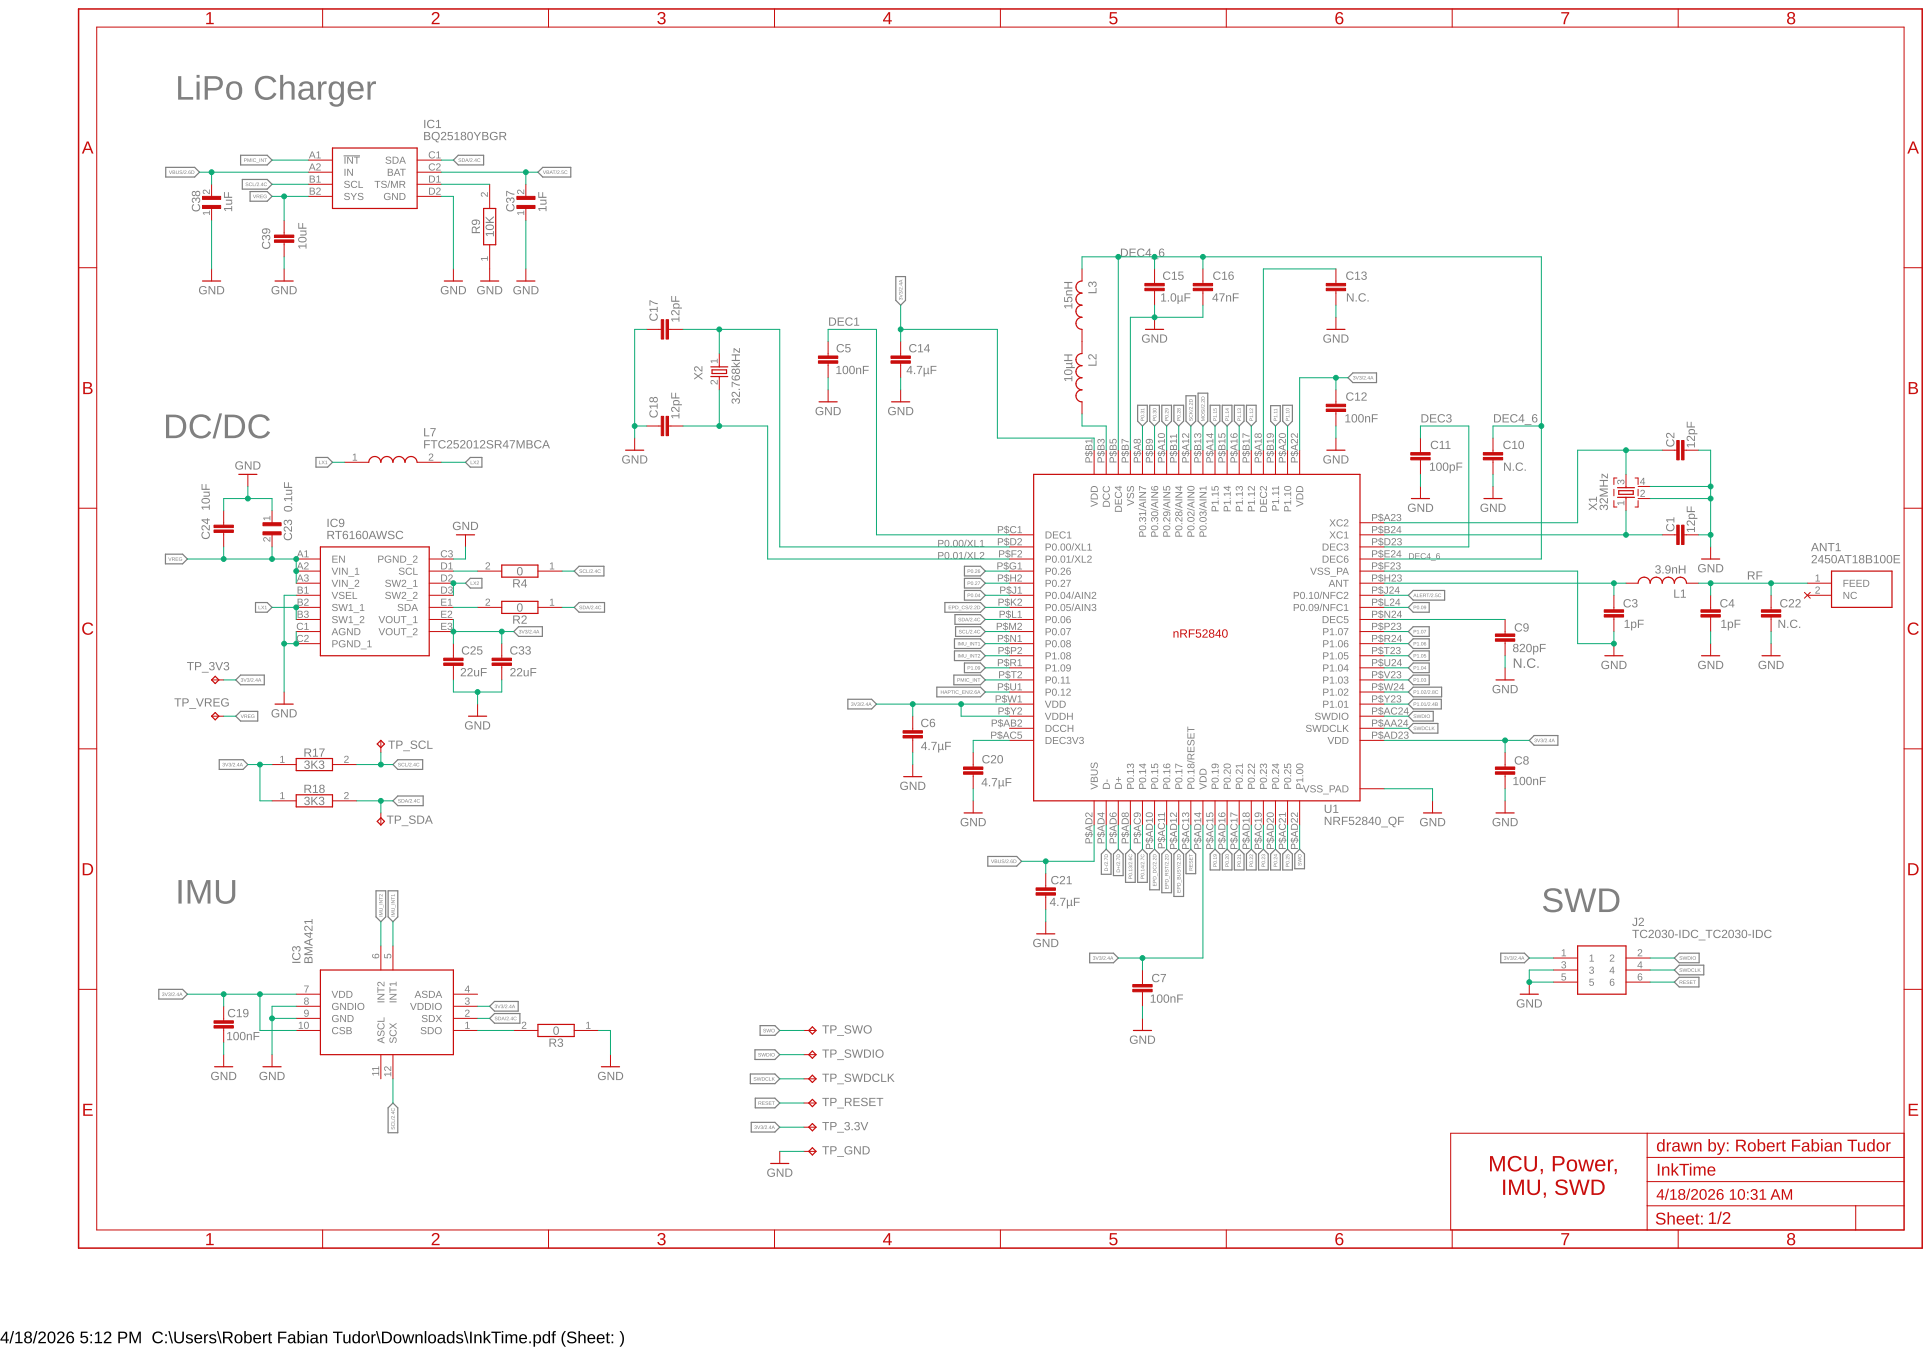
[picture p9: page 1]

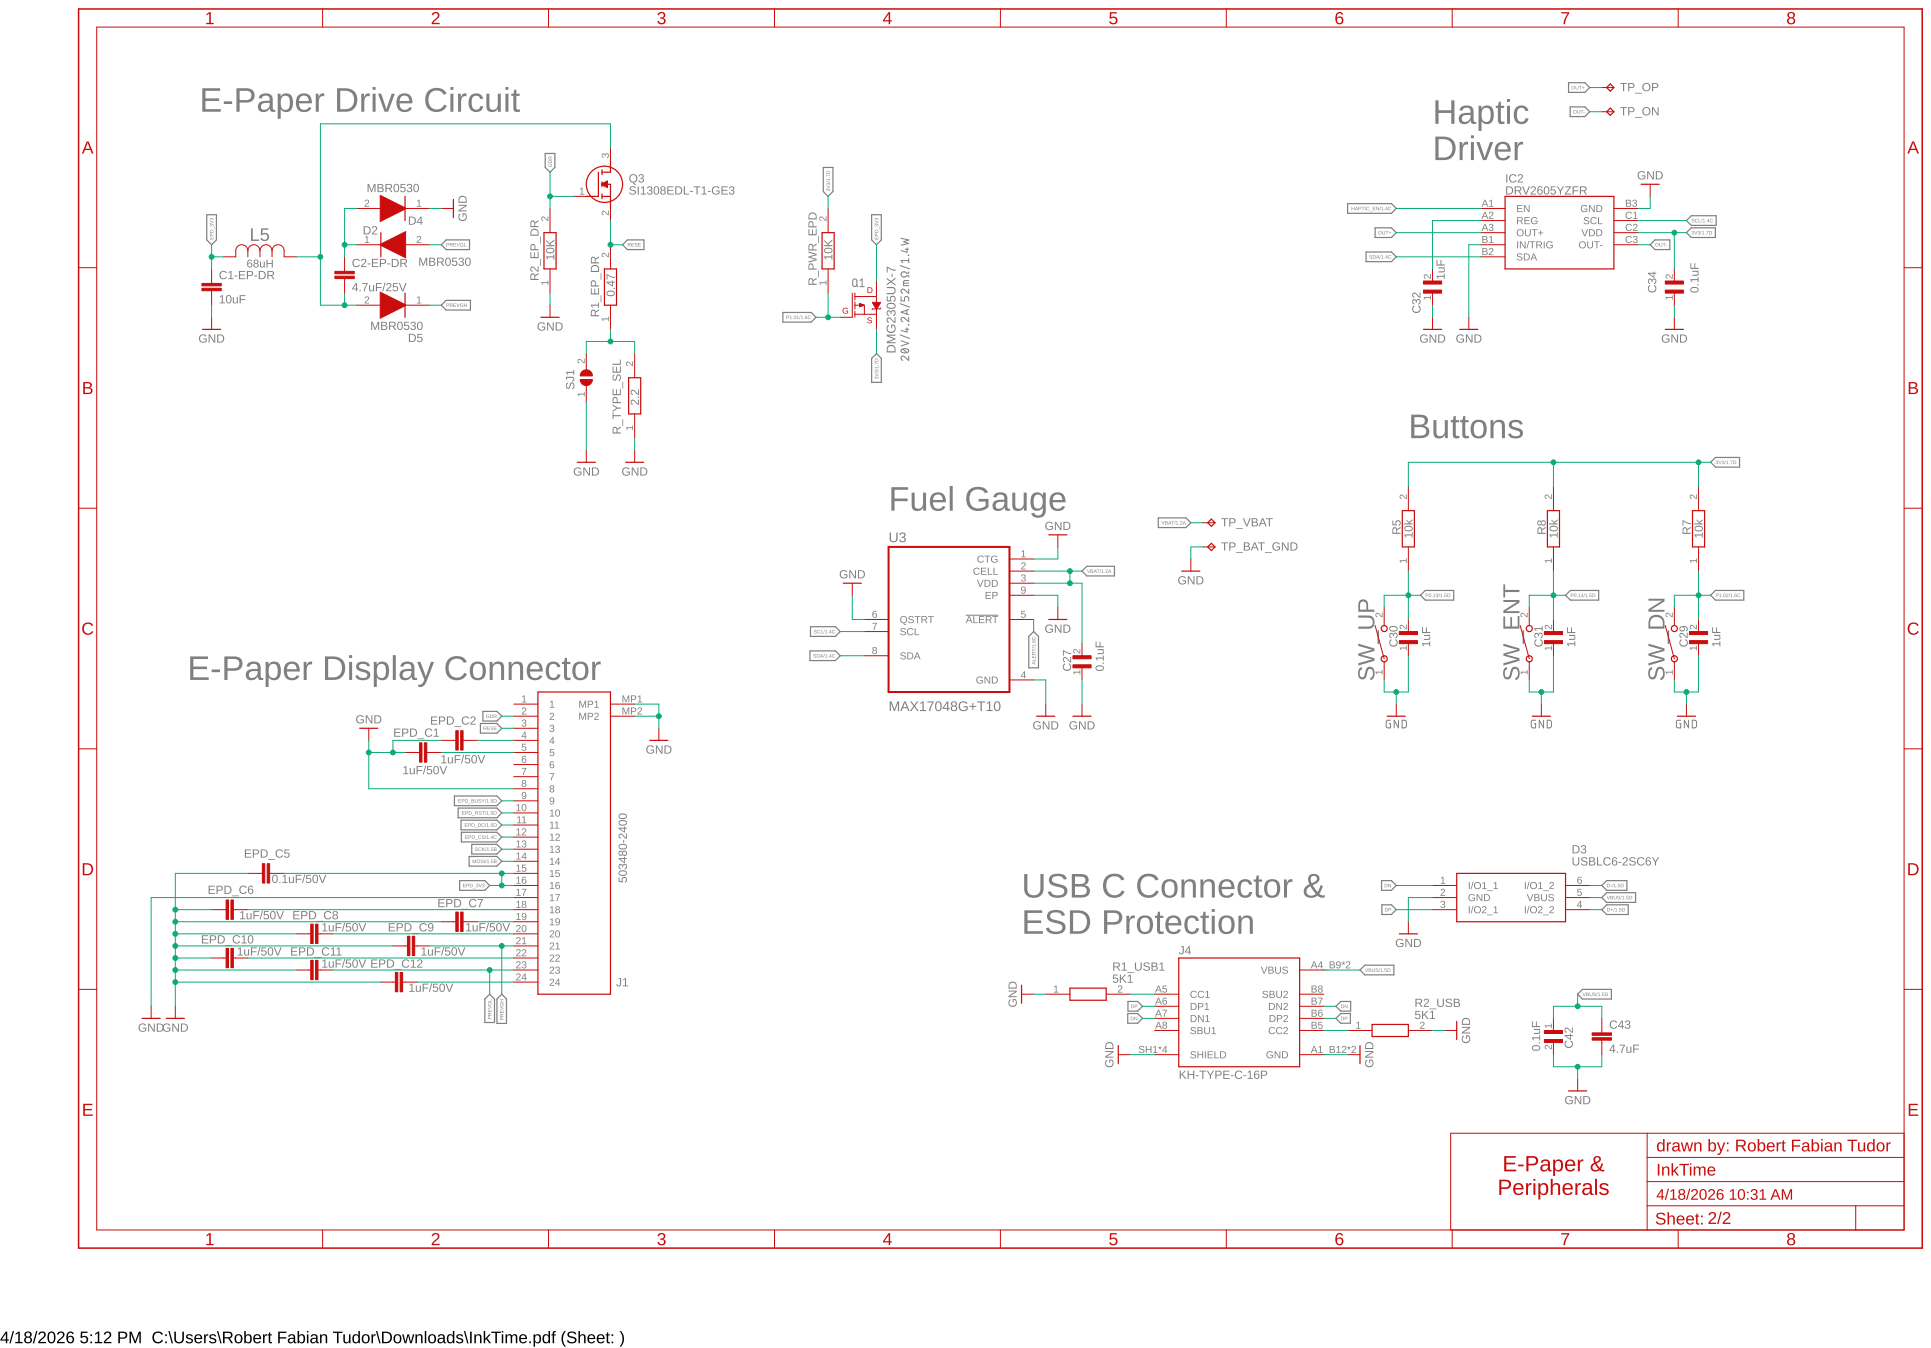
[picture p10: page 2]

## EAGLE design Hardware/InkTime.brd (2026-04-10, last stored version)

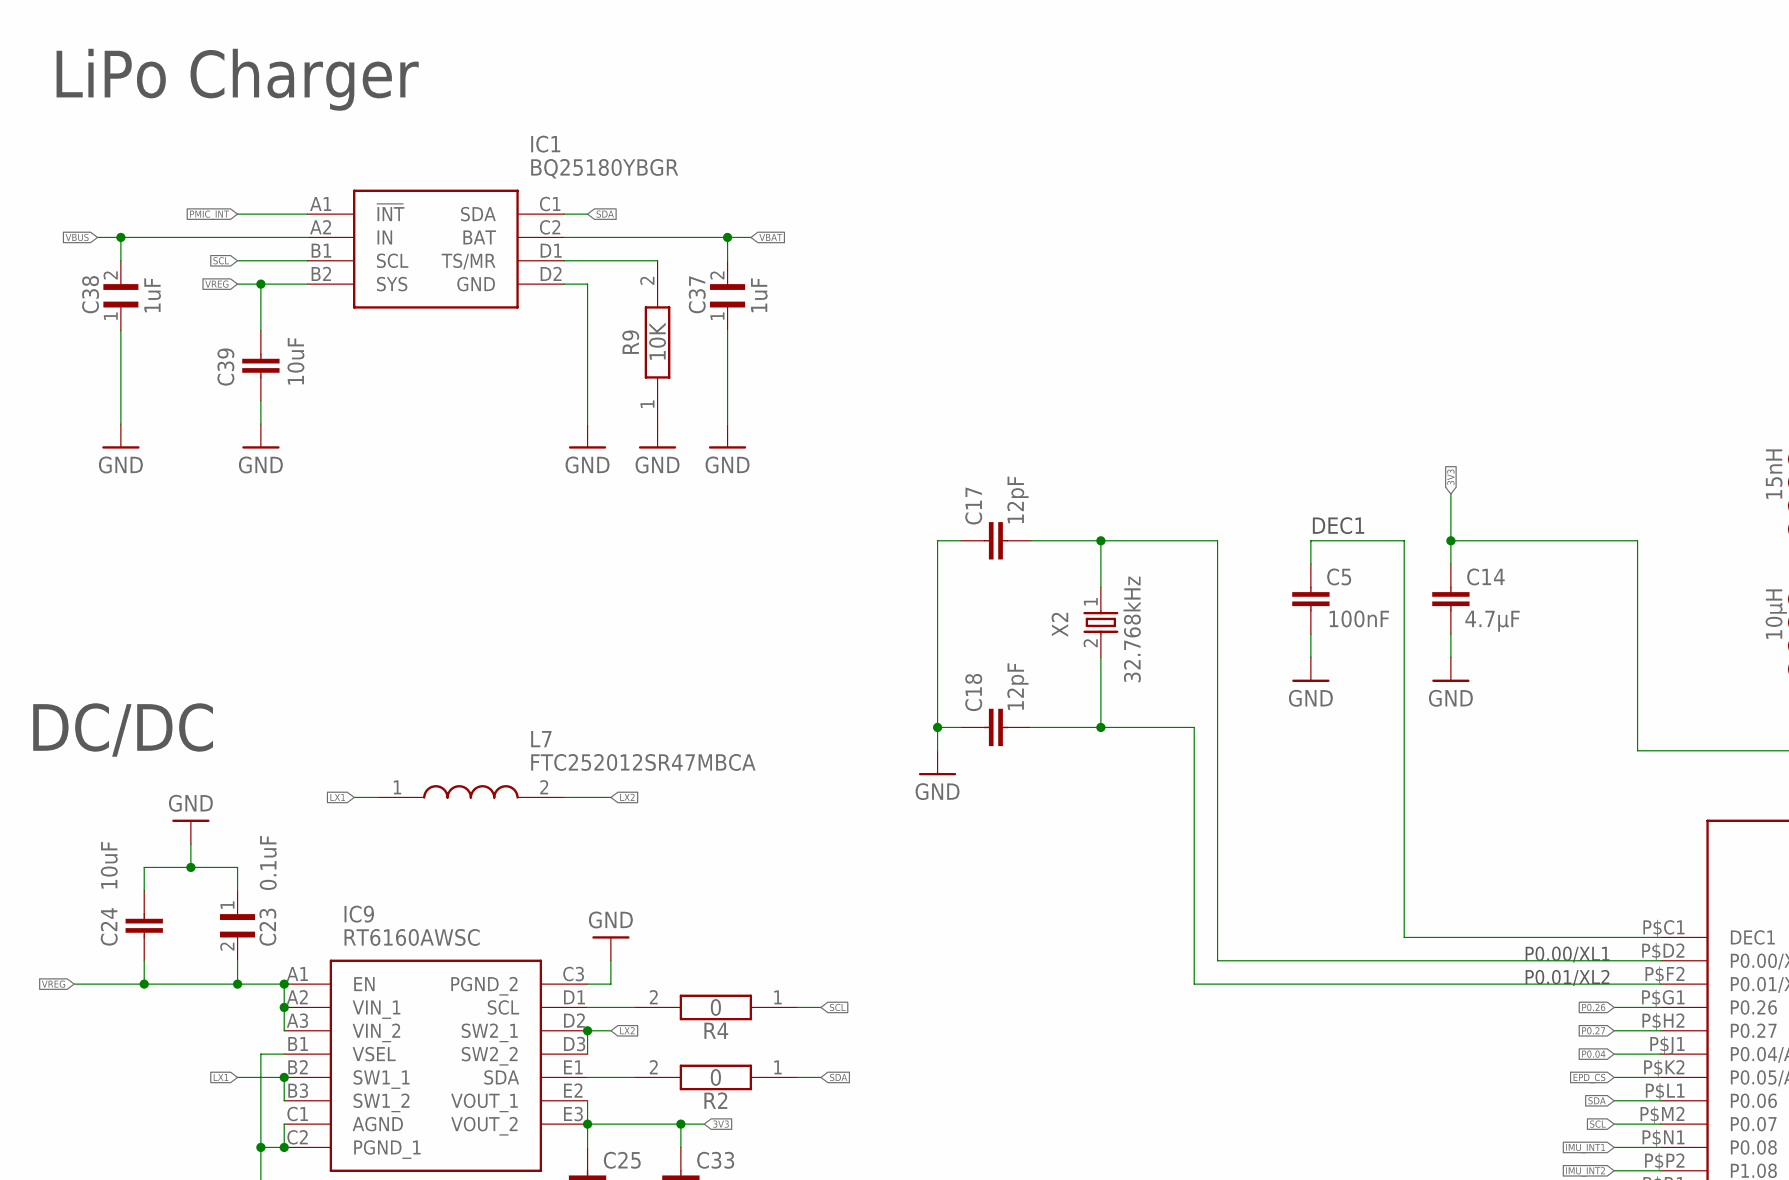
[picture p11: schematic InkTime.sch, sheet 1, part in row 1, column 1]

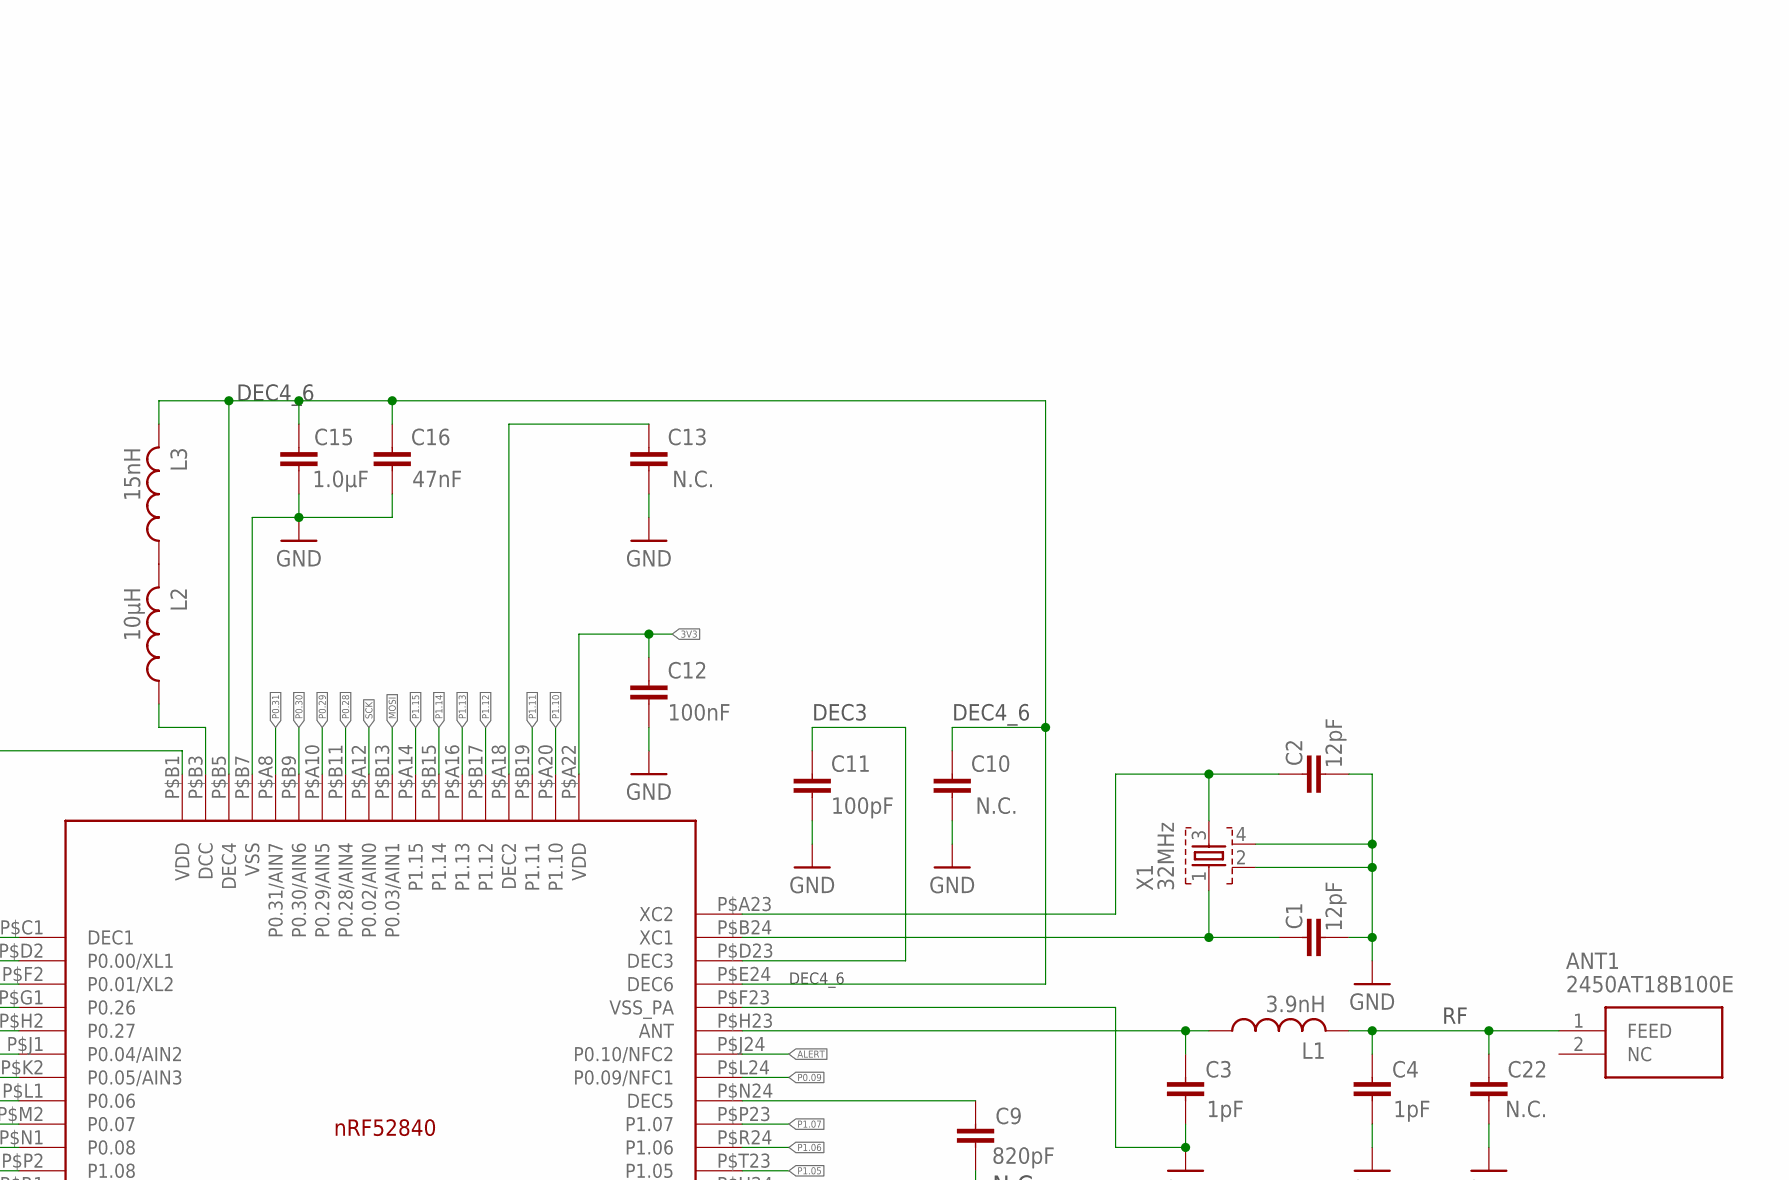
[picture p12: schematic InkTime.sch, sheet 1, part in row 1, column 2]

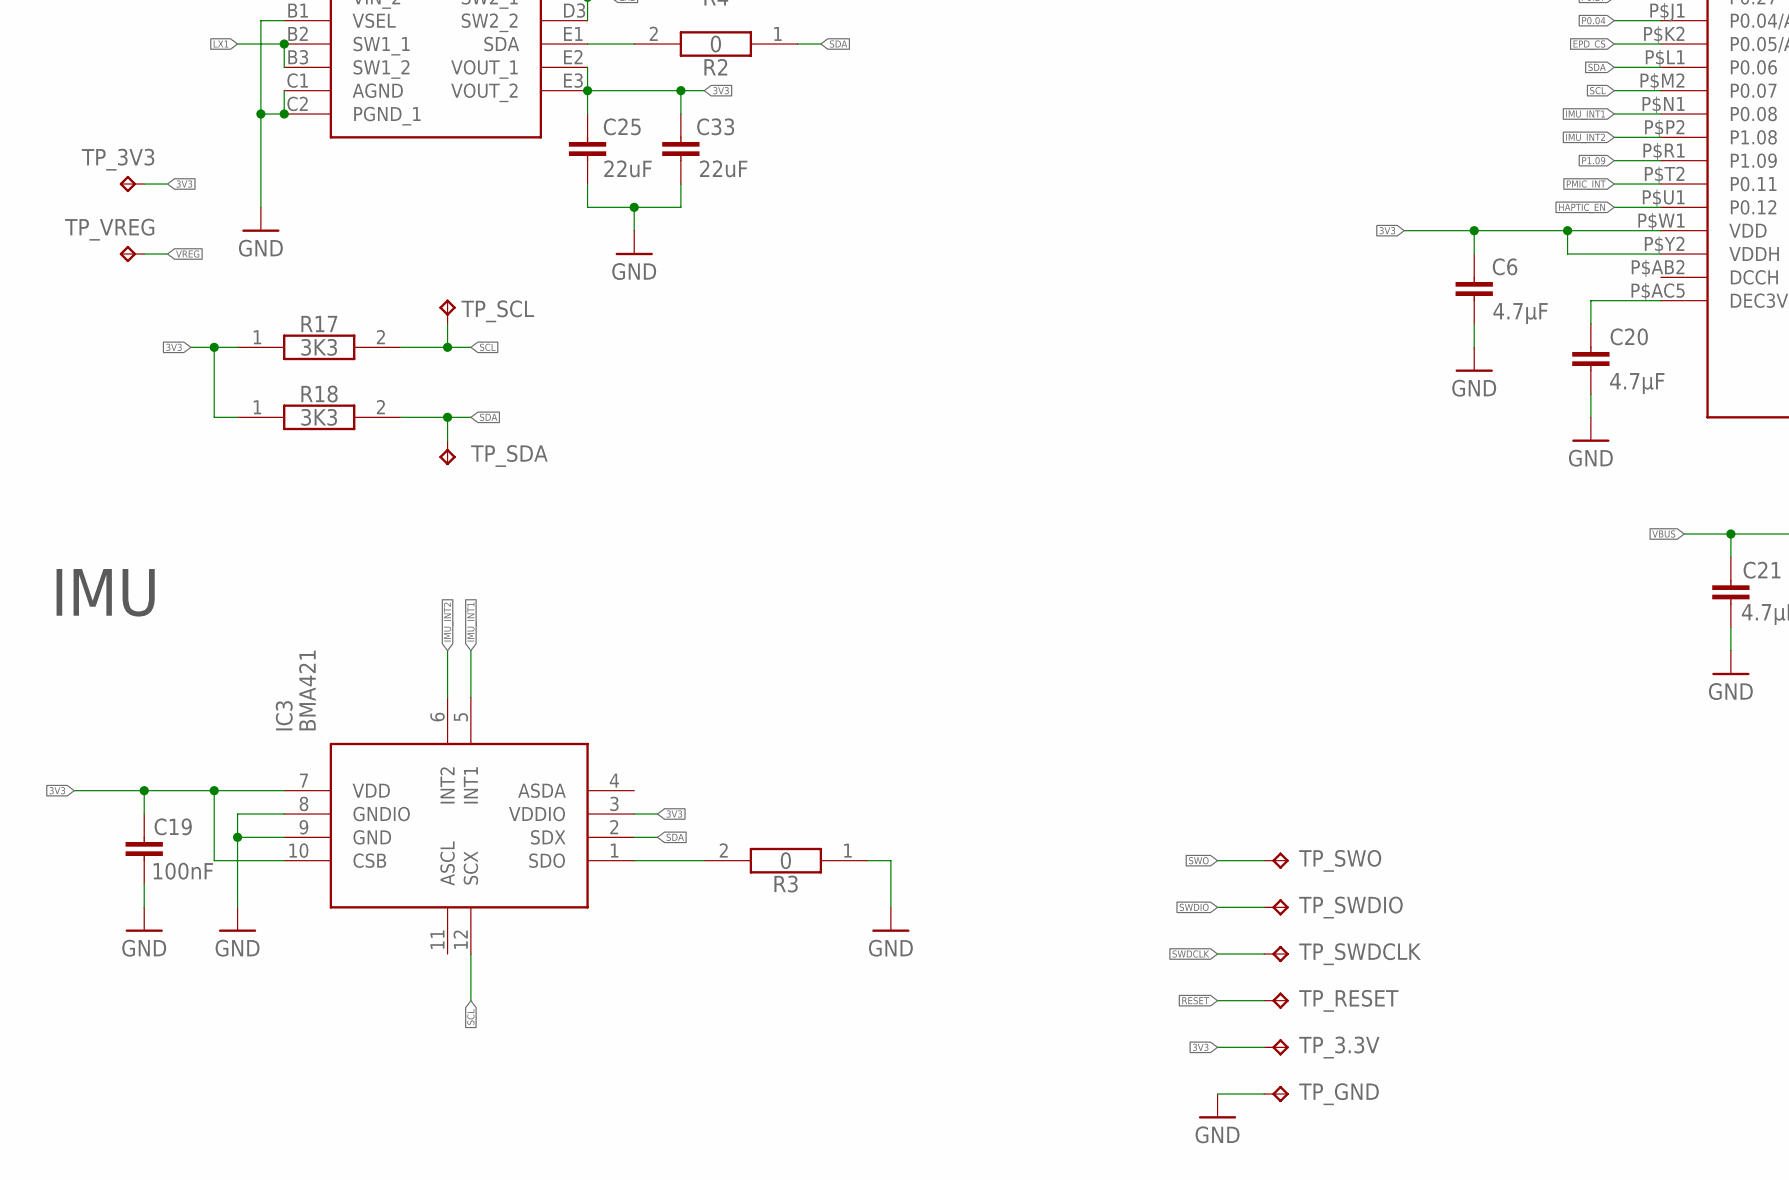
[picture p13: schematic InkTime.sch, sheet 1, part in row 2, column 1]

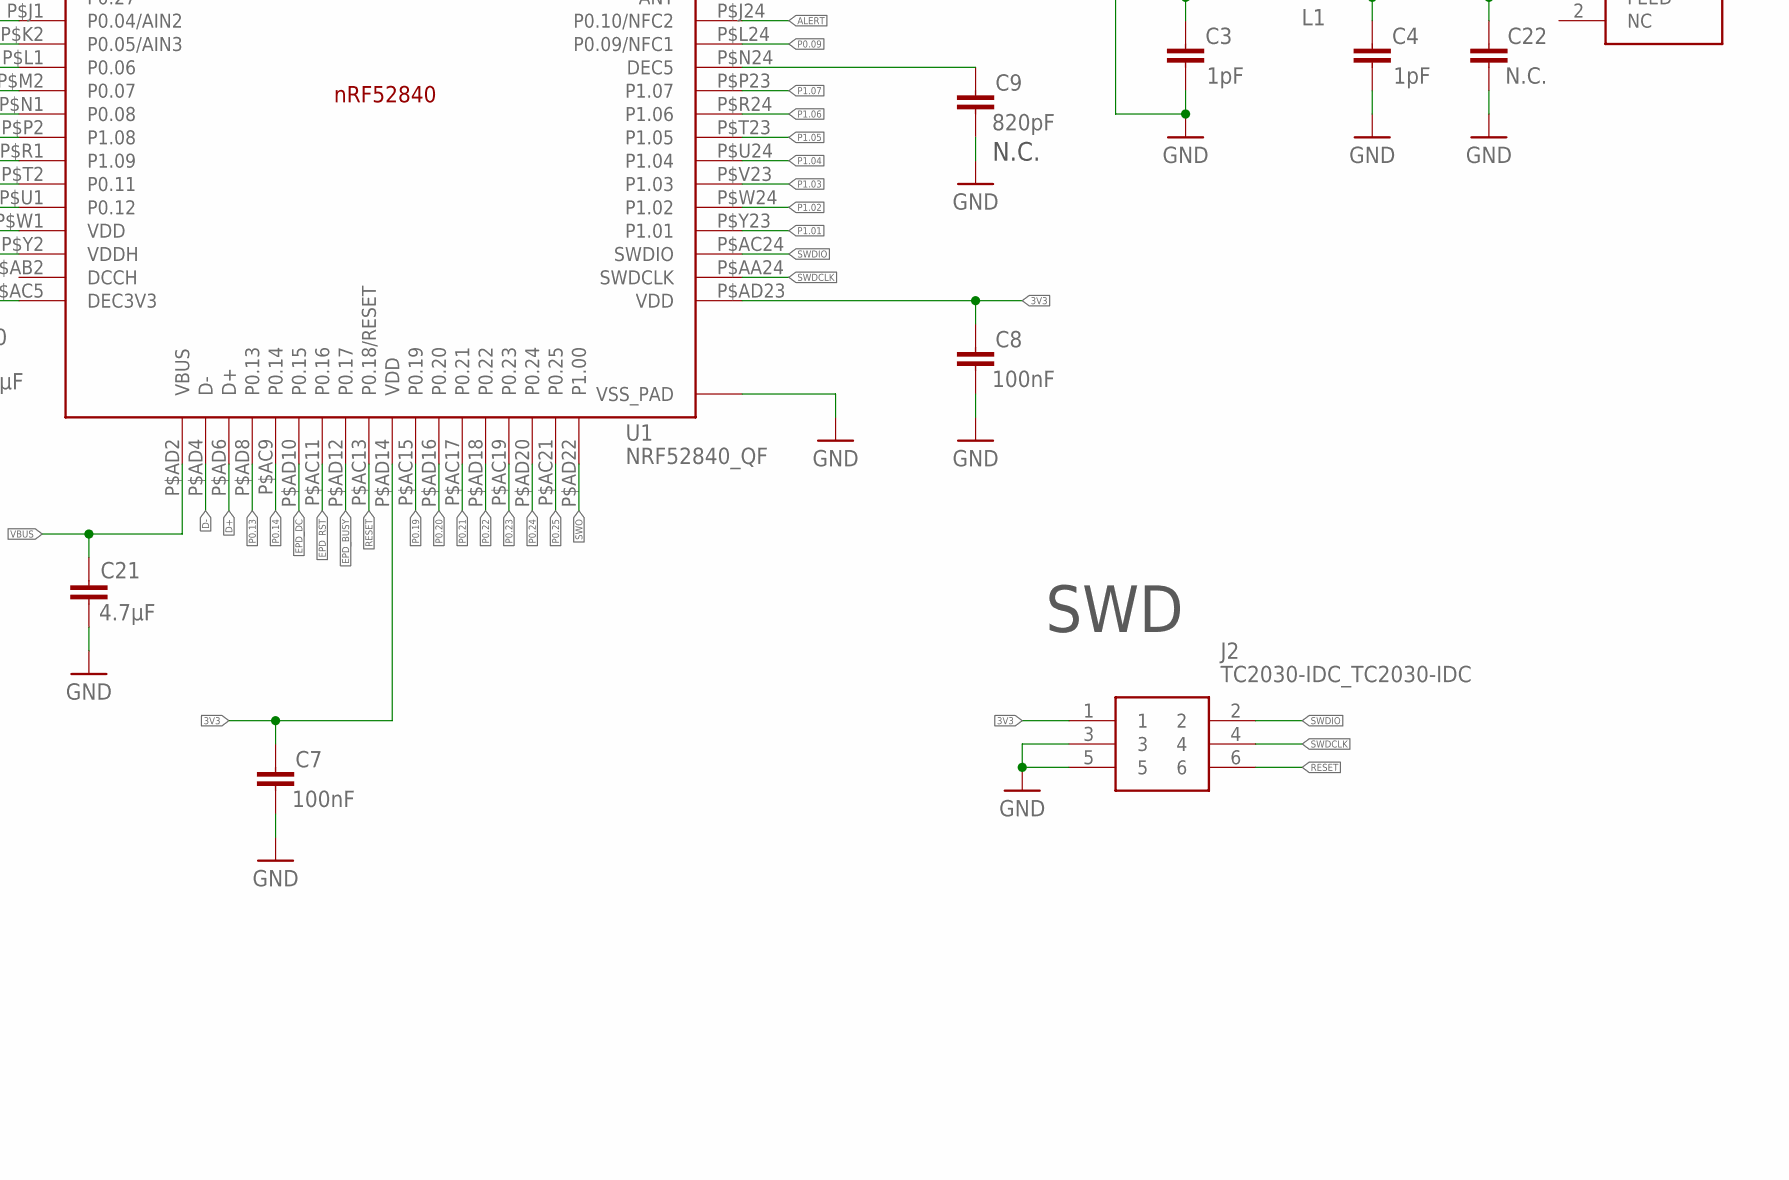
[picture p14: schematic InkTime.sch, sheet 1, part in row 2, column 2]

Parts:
ANT1: 2450AT18B100E; 2450AT18B100E_ANTC3216X140N
C1, C2, C17, C18: 12pF; NORDIC_NRF_3_RESC0201_L
C3, C4: 1pF; NORDIC_NRF_3_RESC0201_L
C5, C7, C8, C12, C19: 100nF; NORDIC_NRF_3_RESC0201_L
C6, C14, C20, C21: 4.7µF; NORDIC_NRF_3_RESC0402_L
C9: 820pF; NORDIC_NRF_3_RESC0201_L
C10, C13, C22: N.C.; NORDIC_NRF_3_RESC0201_L
C11: 100pF; NORDIC_NRF_3_RESC0201_L
C15: 1.0µF; NORDIC_NRF_3_RESC0402_L
C16: 47nF; NORDIC_NRF_3_RESC0201_L
C23: 0.1uF; GRM011R60J152KE01L_1_0201
C24, C39: 10uF; NORDIC_NRF_3_RESC0402_L
C25, C33: 22uF; NORDIC_NRF_3_RESC0402_L
C37, C38: 1uF; GRM011R60J152KE01L_1_0201
IC1: BQ25180YBGR; BQ25180YBGR_BGA8C40P2X4_100X155X50
IC3: BMA421; BMA423_BMA423
IC9: RT6160AWSC; RT6160AWSC_BGA15C40P3X5_140X230X60
J2: TC2030-IDC_TC2030-IDC; TC2030-IDC_TC2030IDC
L1: 3.9nH; NORDIC_NRF_2_RESC0402_L
L2: 10µH; NORDIC_NRF_2_RESC0402_L
L3: 15nH; NORDIC_NRF_2_RESC0402_L
L7: FTC252012SR47MBCA; MLP2016SR47MT0S1_INDC2016X100N
R2, R3, R4: 0; CPF0201D7K68C1_0201
R9: 10K; CPF0201D7K68C1_0201
R17, R18: 3K3; CPF0201D7K68C1_0201
TP_3.3V, TP_3V3: HECTOR_WATCH_1_TPTP20R; HECTOR_WATCH_1_TP20R
TP_GND: HECTOR_WATCH_1_TPTP20R; HECTOR_WATCH_1_TP20R
TP_RESET: HECTOR_WATCH_1_TPTP20R; HECTOR_WATCH_1_TP20R
TP_SCL: HECTOR_WATCH_1_TPTP20R; HECTOR_WATCH_1_TP20R
TP_SDA: HECTOR_WATCH_1_TPTP20R; HECTOR_WATCH_1_TP20R
TP_SWDCLK: HECTOR_WATCH_1_TPTP20R; HECTOR_WATCH_1_TP20R
TP_SWDIO: HECTOR_WATCH_1_TPTP20R; HECTOR_WATCH_1_TP20R
TP_SWO: HECTOR_WATCH_1_TPTP20R; HECTOR_WATCH_1_TP20R
TP_VREG: HECTOR_WATCH_1_TPTP20R; HECTOR_WATCH_1_TP20R
U1: NRF52840_QF; NORDIC_NRF_4_AQFN50P700X700X85_HS-74N
X1: 32MHz; NORDIC_NRF_BT-XTAL_2016_N
X2: 32.768kHz; NORDIC_NRF_1_XTAL_3215_N

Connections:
3V3: C6.1, C7.1, C8.1, C12.1, C14.1, C19.1, C25.1, C33.1, IC3.3 (VDDIO), IC3.7 (VDD), IC3.10 (CSB), IC9.E2 (VOUT_1), IC9.E3 (VOUT_2), J2.1, R17.1, R18.1, TP_3.3V.TP, TP_3V3.TP, U1.P$A22 (VDD), U1.P$AD14 (VDD), U1.P$AD23 (VDD), U1.P$B1 (VDD), U1.P$W1 (VDD), U1.P$Y2 (VDDH); also elsewhere on the board
ALERT: U1.P$J24 (P0.10/NFC2); also elsewhere on the board
D+: U1.P$AD6 (D+); also elsewhere on the board
D-: U1.P$AD4 (D-); also elsewhere on the board
EPD_BUSY: U1.P$AD12 (P0.17); also elsewhere on the board
EPD_CS: U1.P$K2 (P0.05/AIN3); also elsewhere on the board
EPD_DC: U1.P$AD10 (P0.15); also elsewhere on the board
EPD_RST: U1.P$AC11 (P0.16); also elsewhere on the board
GND: C1.2, C2.2, C3.2, C4.2, C5.2, C6.2, C7.2, C8.2, C9.2, C10.2, C11.2, C12.2, C13.2, C14.2, C15.2, C16.2, C17.1, C18.1, C19.2, C20.2, C21.2, C22.2, C23.1, C24.1, C25.2, C33.2, C37.1, C38.1, C39.2, IC1.D2 (GND), IC3.8 (GNDIO), IC3.9 (GND), IC9.B1 (VSEL), IC9.C1 (AGND), IC9.C2 (PGND_1), IC9.C3 (PGND_2), J2.3, J2.5, R3.1, R9.1, TP_GND.TP, U1.P$74 (VSS_PAD), U1.P$75 (VSS_PAD), U1.P$76 (VSS_PAD), U1.P$77 (VSS_PAD), U1.P$78 (VSS_PAD), U1.P$79 (VSS_PAD), U1.P$80 (VSS_PAD), U1.P$81 (VSS_PAD), U1.P$82 (VSS_PAD), U1.P$83 (VSS_PAD), U1.P$84 (VSS_PAD), U1.P$85 (VSS_PAD), U1.P$86 (VSS_PAD), U1.P$87 (VSS_PAD), U1.P$88 (VSS_PAD), U1.P$89 (VSS_PAD), U1.P$90 (VSS_PAD), U1.P$B7 (VSS), U1.P$F23 (VSS_PA), X1.2, X1.4; also elsewhere on the board
HAPTIC_EN: U1.P$U1 (P0.12); also elsewhere on the board
IMU_INT1: IC3.5 (INT1), U1.P$N1 (P0.08)
IMU_INT2: IC3.6 (INT2), U1.P$P2 (P1.08)
LX1: IC9.B2 (SW1_1), IC9.B3 (SW1_2), L7.1
LX2: IC9.D2 (SW2_1), IC9.D3 (SW2_2), L7.2
MOSI: U1.P$B13 (P0.03/AIN1); also elsewhere on the board
unnamed: C9.1, U1.P$N24 (DEC5)
unnamed: C3.1, L1.1, U1.P$H23 (ANT)
unnamed: C13.1, U1.P$A18 (DEC2)
unnamed: L2.1, U1.P$B3 (DCC)
unnamed: IC1.D1 (TS/MR), R9.2
unnamed: C11.1, U1.P$D23 (DEC3)
unnamed: C1.1, U1.P$B24 (XC1), X1.1
unnamed: C2.1, U1.P$A23 (XC2), X1.3
unnamed: ANT1.1 (FEED), C4.1, C22.1, L1.2
unnamed: C10.1, C15.1, C16.1, L3.2, U1.P$B5 (DEC4), U1.P$E24 (DEC6)
unnamed: L2.2, L3.1
unnamed: C5.1, U1.P$C1 (DEC1)
unnamed: C17.2, U1.P$D2 (P0.00/XL1), X2.1
unnamed: C18.2, U1.P$F2 (P0.01/XL2), X2.2
unnamed: C20.1, U1.P$AC5 (DEC3V3)
unnamed: IC9.E1 (SDA), R2.2
unnamed: IC9.D1 (SCL), R4.2
unnamed: IC3.1 (SDO), R3.2
P0.04: U1.P$J1 (P0.04/AIN2)
P0.09: U1.P$L24 (P0.09/NFC1)
P0.13: U1.P$AD8 (P0.13); also elsewhere on the board
P0.14: U1.P$AC9 (P0.14); also elsewhere on the board
P0.19: U1.P$AC15 (P0.19)
P0.20: U1.P$AD16 (P0.20)
P0.21: U1.P$AC17 (P0.21)
P0.22: U1.P$AD18 (P0.22)
P0.23: U1.P$AC19 (P0.23)
P0.24: U1.P$AD20 (P0.24)
P0.25: U1.P$AC21 (P0.25)
P0.26: U1.P$G1 (P0.26)
P0.27: U1.P$H2 (P0.27)
P0.28: U1.P$B11 (P0.28/AIN4)
P0.29: U1.P$A10 (P0.29/AIN5)
P0.30: U1.P$B9 (P0.30/AIN6)
P0.31: U1.P$A8 (P0.31/AIN7)
P1.01: U1.P$Y23 (P1.01); also elsewhere on the board
P1.02: U1.P$W24 (P1.02); also elsewhere on the board
P1.03: U1.P$V23 (P1.03)
P1.04: U1.P$U24 (P1.04)
P1.05: U1.P$T23 (P1.05)
P1.06: U1.P$R24 (P1.06)
P1.07: U1.P$P23 (P1.07)
P1.09: U1.P$R1 (P1.09)
P1.10: U1.P$A20 (P1.10)
P1.11: U1.P$B19 (P1.11)
P1.12: U1.P$B17 (P1.12)
P1.13: U1.P$A16 (P1.13)
P1.14: U1.P$B15 (P1.14)
P1.15: U1.P$A14 (P1.15)
PMIC_INT: IC1.A1 (!INT), U1.P$T2 (P0.11)
RESET: J2.6, TP_RESET.TP, U1.P$AC13 (P0.18/RESET)
SCK: U1.P$A12 (P0.02/AIN0); also elsewhere on the board
SCL: IC1.B1 (SCL), IC3.12 (SCX), R4.1, R17.2, TP_SCL.TP, U1.P$M2 (P0.07); also elsewhere on the board
SDA: IC1.C1 (SDA), IC3.2 (SDX), R2.1, R18.2, TP_SDA.TP, U1.P$L1 (P0.06); also elsewhere on the board
SWDCLK: J2.4, TP_SWDCLK.TP, U1.P$AA24 (SWDCLK)
SWDIO: J2.2, TP_SWDIO.TP, U1.P$AC24 (SWDIO)
SWO: TP_SWO.TP, U1.P$AD22 (P1.00)
VBAT: C37.2, IC1.C2 (BAT); also elsewhere on the board
VBUS: C21.1, C38.2, IC1.A2 (IN), U1.P$AD2 (VBUS); also elsewhere on the board
VREG: C23.2, C24.2, C39.1, IC1.B2 (SYS), IC9.A1 (EN), IC9.A2 (VIN_1), IC9.A3 (VIN_2), TP_VREG.TP

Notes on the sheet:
SWD
LiPo Charger
N.C.
DEC3
DEC4_6
DEC1
P0.00/XL1
P0.01/XL2
DC/DC
IMU

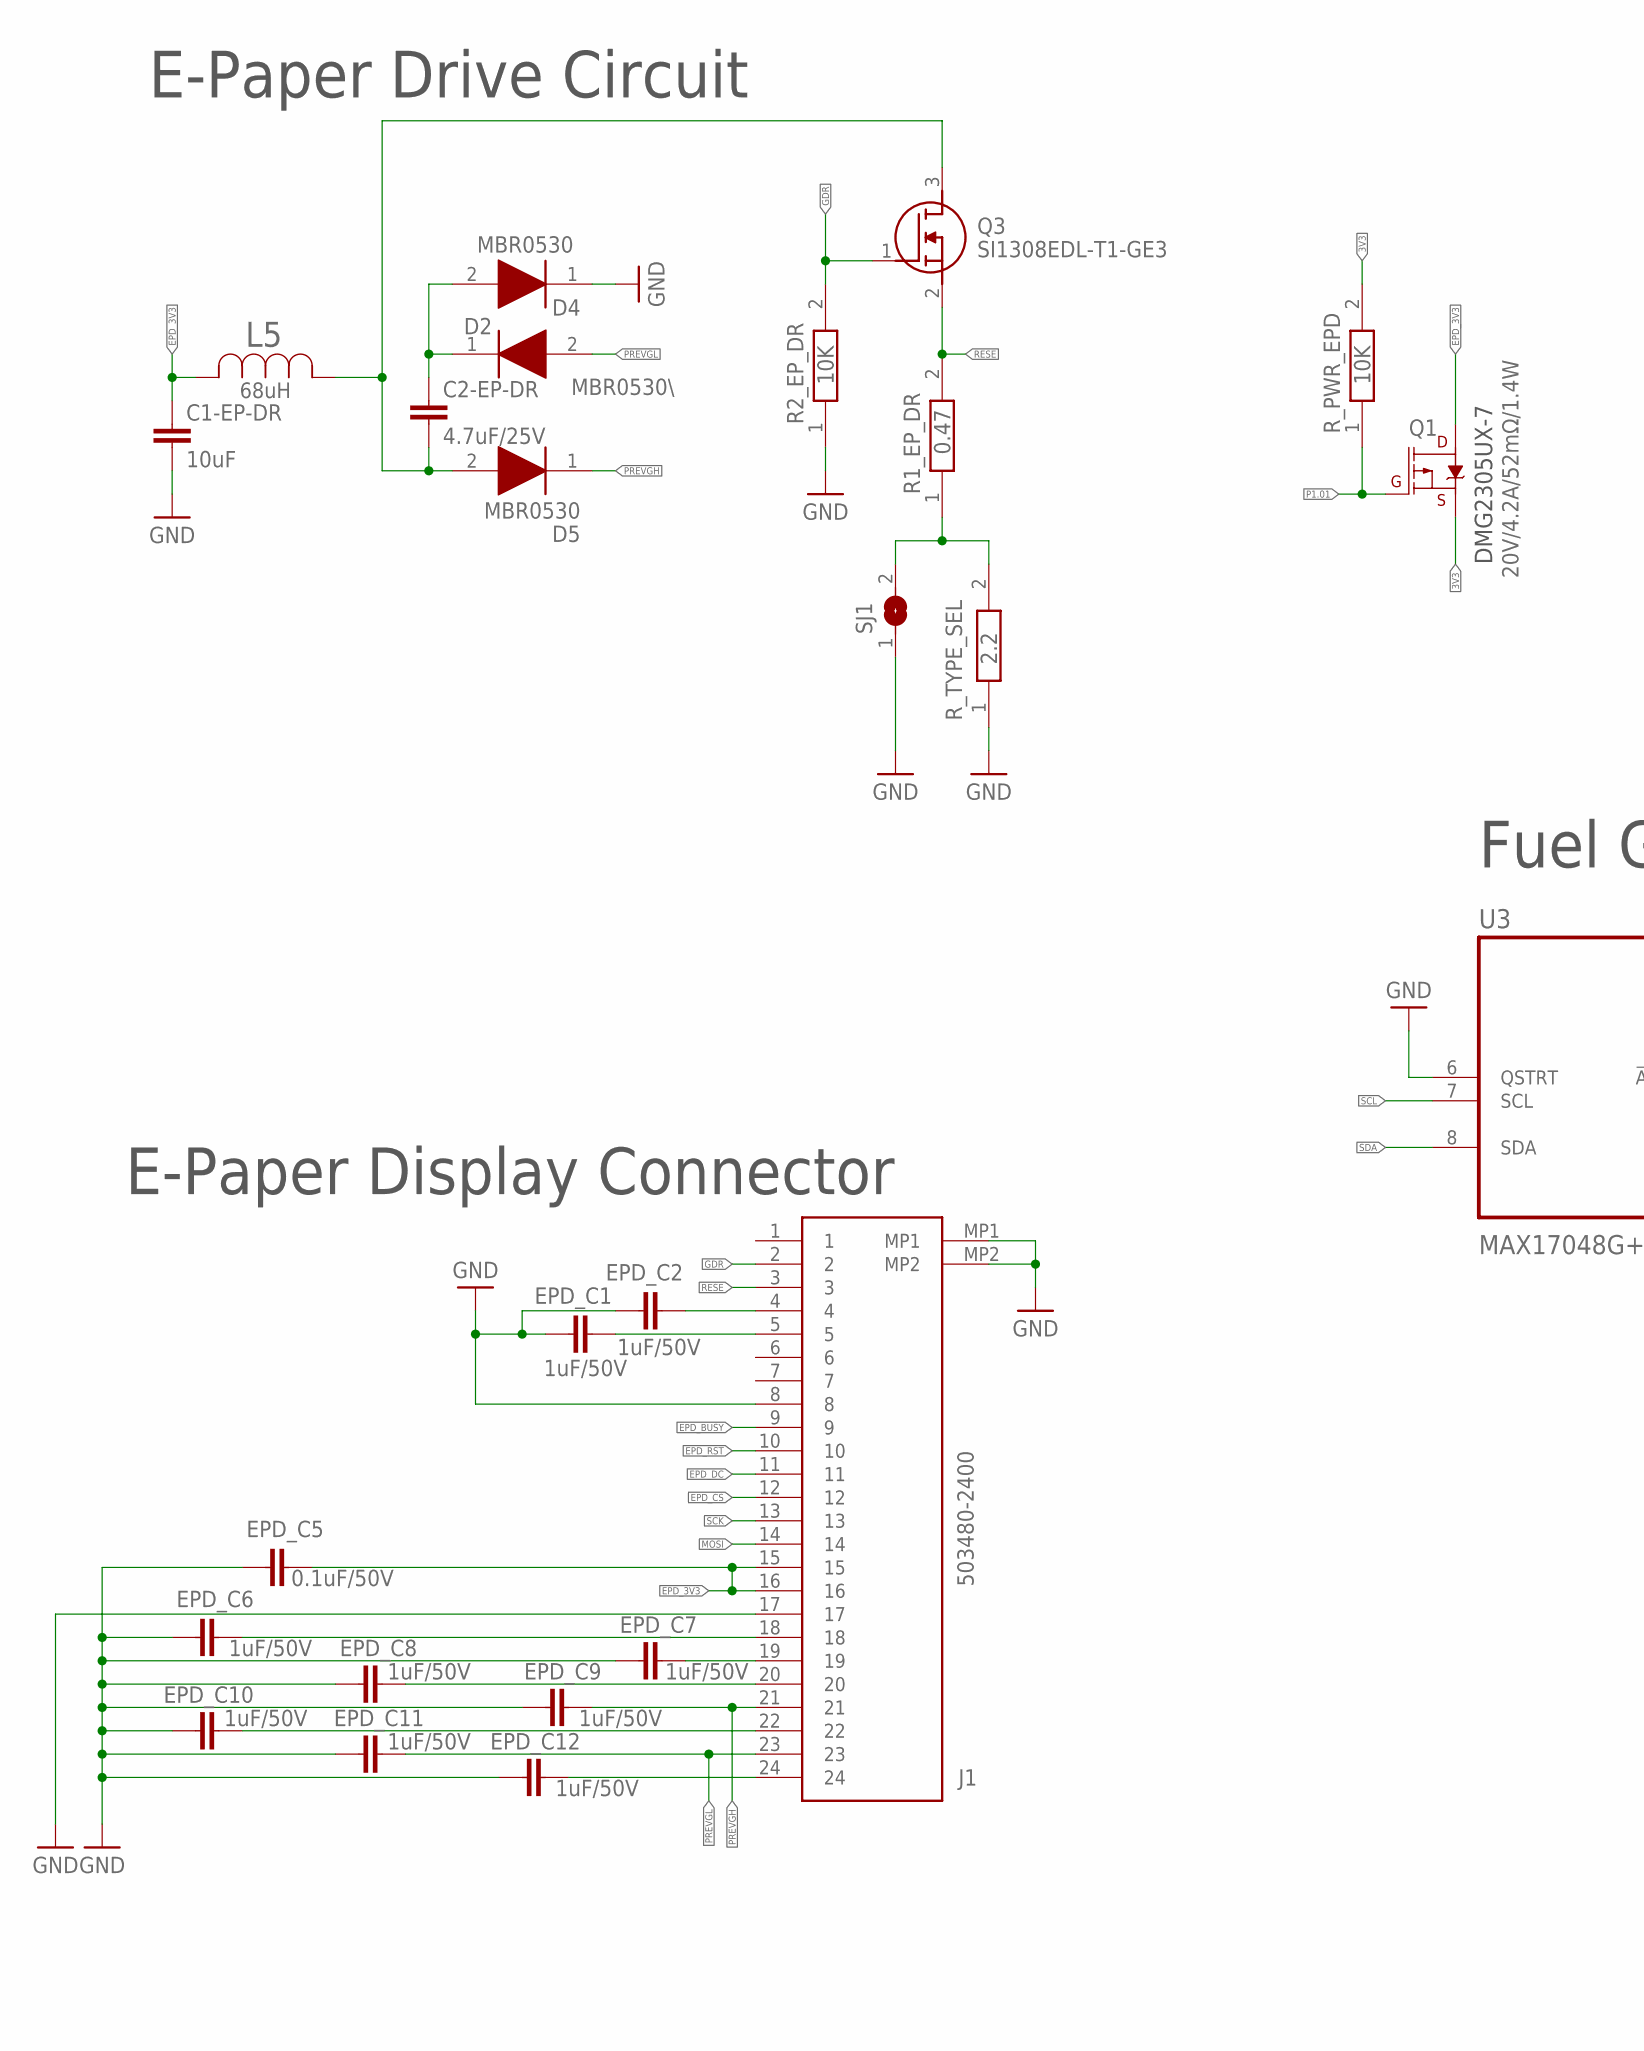
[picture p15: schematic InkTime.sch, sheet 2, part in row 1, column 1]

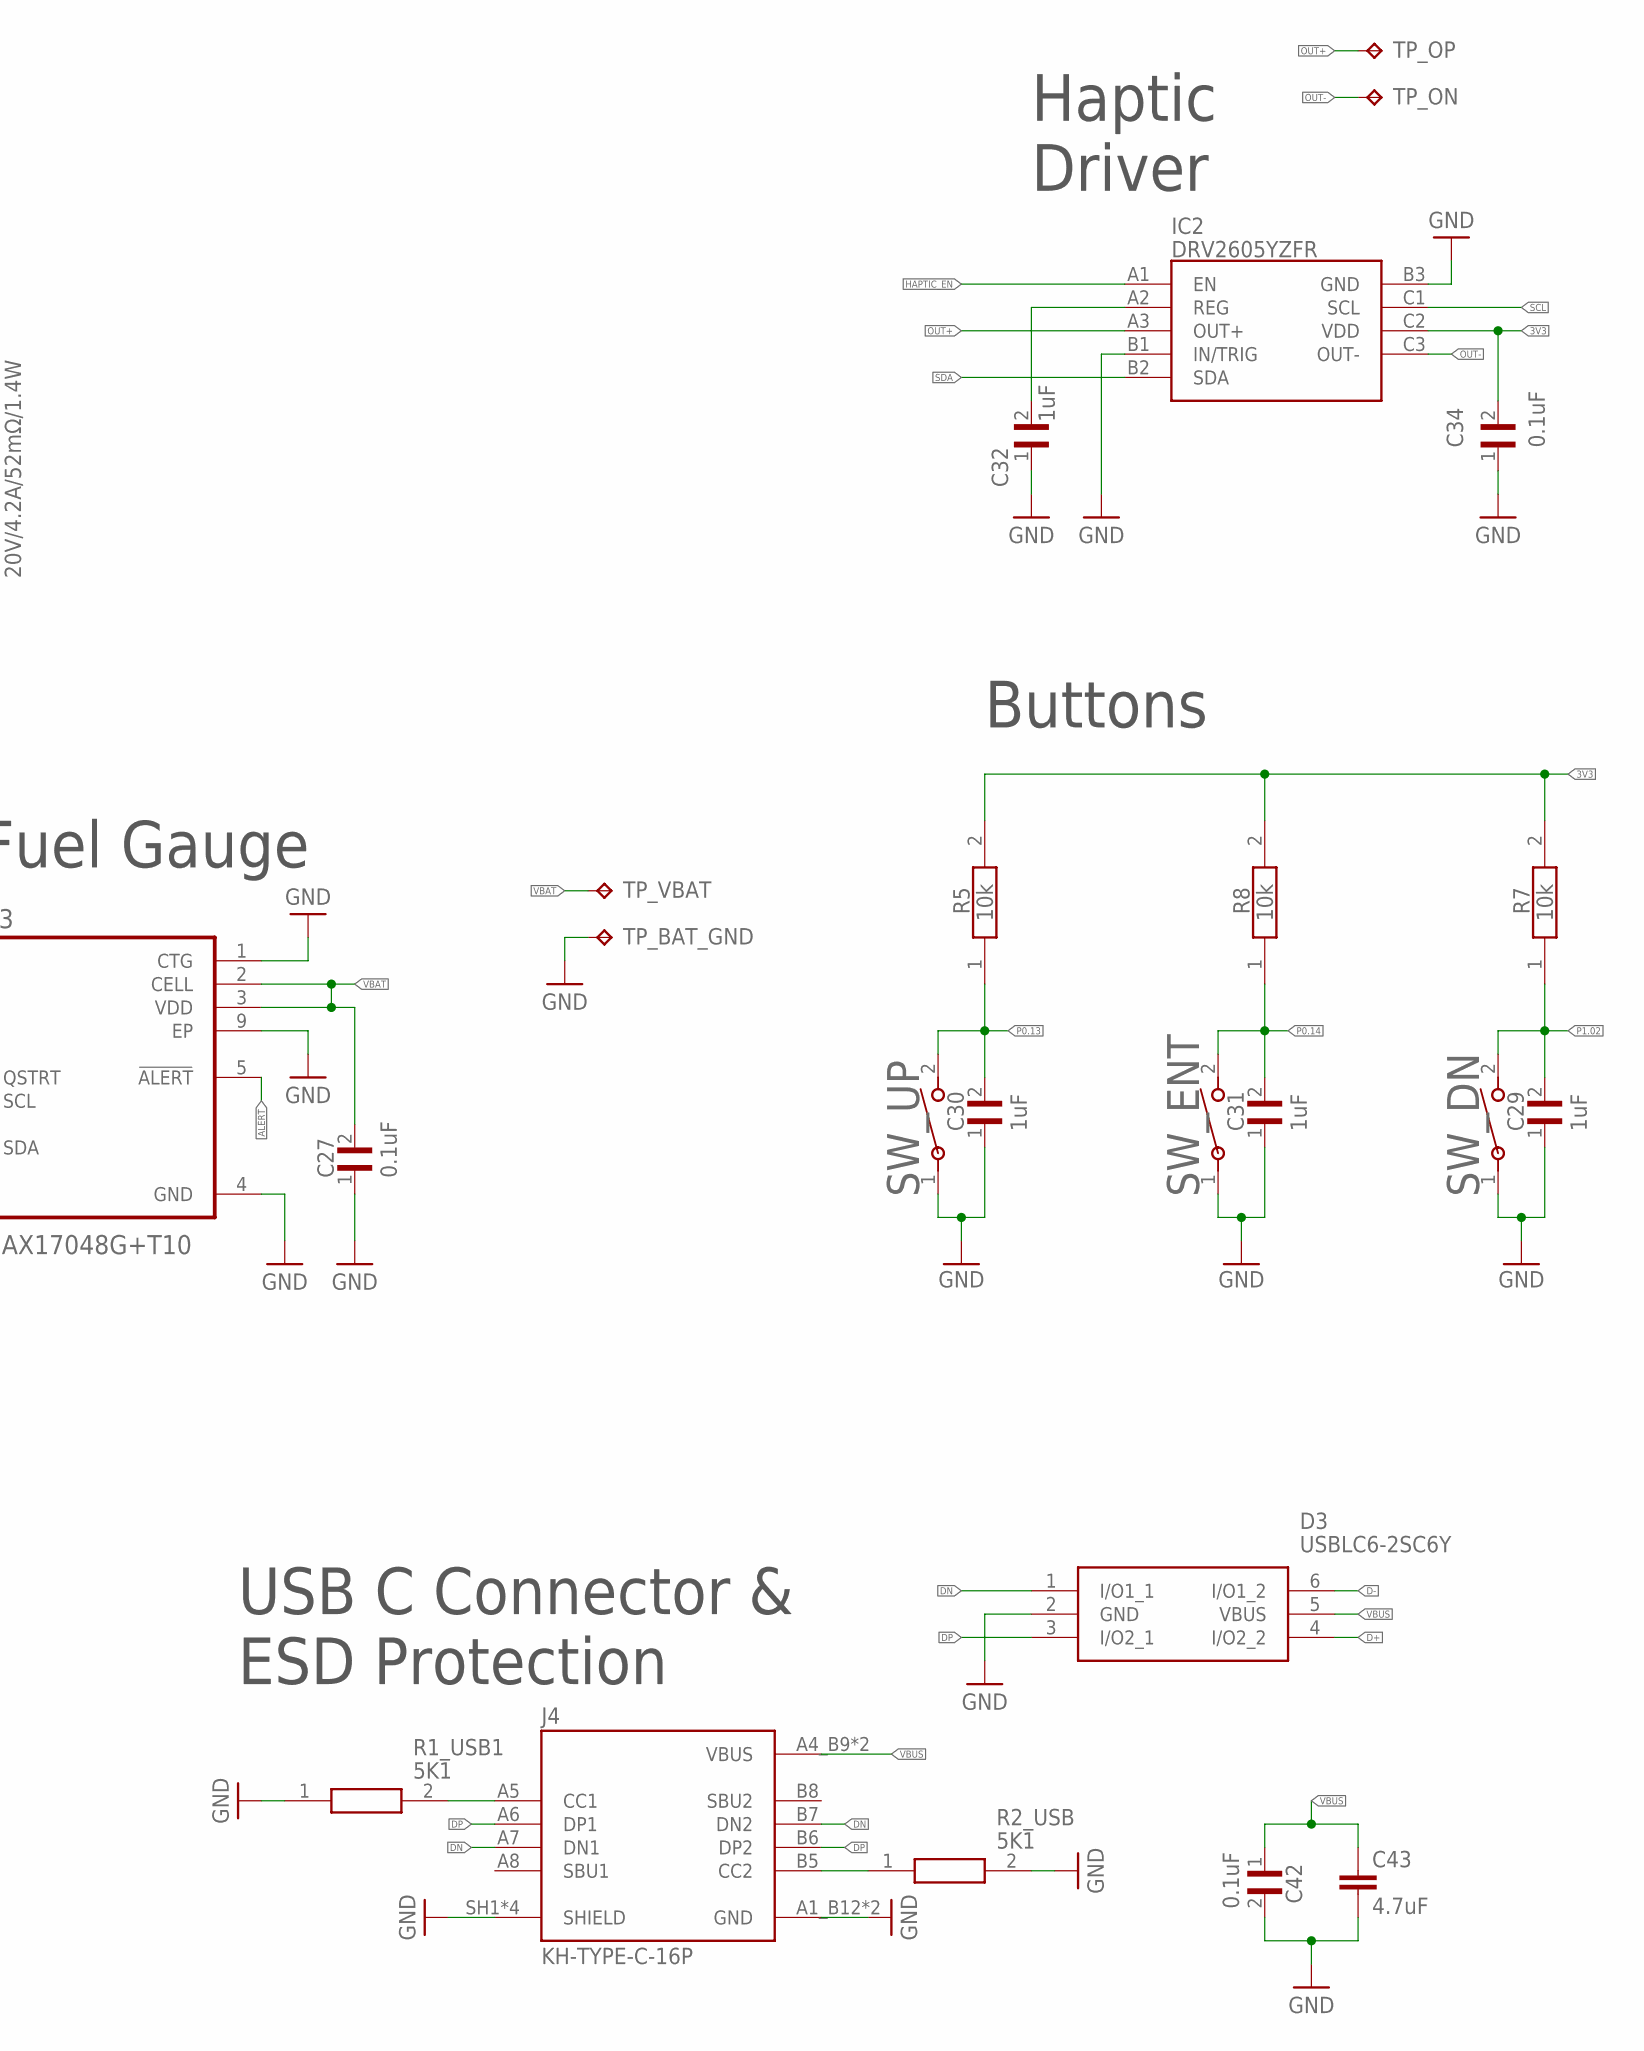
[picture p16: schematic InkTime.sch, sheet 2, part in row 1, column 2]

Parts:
C1-EP-DR: 10uF; NORDIC_NRF_3_RESC0402_L
C2-EP-DR: 4.7uF/25V; NORDIC_NRF_3_RESC0402_L
C27, C34, C42: 0.1uF; GRM011R60J152KE01L_1_0201
C29, C30, C31, C32: 1uF; GRM011R60J152KE01L_1_0201
C43: 4.7uF; NORDIC_NRF_3_RESC0402_L
D2: MBR0530\; ESP32_C6_LIBRARY_5_SOD3716X135N
D3: USBLC6-2SC6Y; ESP32_C6_LIBRARY_3_SOT95P280X145-6N
D4, D5: MBR0530; ESP32_C6_LIBRARY_5_SOD3716X135N
EPD_C1, EPD_C2, EPD_C6, EPD_C7, EPD_C8, EPD_C9, EPD_C10, EPD_C11, EPD_C12: 1uF/50V; NORDIC_NRF_3_RESC0402_L
EPD_C5: 0.1uF/50V; NORDIC_NRF_3_RESC0201_L
IC2: DRV2605YZFR; DRV2605YZFR_BGA9C50P3X3_144X144X62
J1: 503480-2400; 503480-2400_5034802400
J4: KH-TYPE-C-16P; KH-TYPE-C-16P_KINGHELM_KH-TYPE-C-16P
L5: 68uH; ESP32_C6_LIBRARY_2_IND_4828-WE-TPC_WRE
Q1: 20V/4.2A/52mΩ/1.4W; ESP32_C6_LIBRARY_4_ESP32_C6_LIBRARY_4_ESP32_C6_LIBRARY_4_ES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
Q3: SI1308EDL-T1-GE3; ESP32_C6_LIBRARY_6_SOT65P210X110-3N
R1_EP_DR: 0.47; CPF0201D7K68C1_0201
R1_USB1, R2_USB: 5K1; CPF0201D7K68C1_0201
R2_EP_DR: 10K; CPF0201D7K68C1_0201
R5, R7, R8: 10k; CPF0201D7K68C1_0201
R_PWR_EPD: 10K; CPF0201D7K68C1_0201
R_TYPE_SEL: 2.2; CPF0201D7K68C1_0201
SJ1: ESP32_C6_LIBRARY_7_JUMPER_SJ
SW_DN: 2025-10-22_07-23-44_LIBRARY_EVP-AKE31ASW_EVP-AKE3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; 2025-10-22_07-23-44_LIBRARY_SW_EVP-AKE31A_PAN
SW_ENT: 2025-10-22_07-23-44_LIBRARY_EVP-AKE31ASW_EVP-AKE3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; 2025-10-22_07-23-44_LIBRARY_SW_EVP-AKE31A_PAN
SW_UP: 2025-10-22_07-23-44_LIBRARY_EVP-AKE31ASW_EVP-AKE3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; 2025-10-22_07-23-44_LIBRARY_SW_EVP-AKE31A_PAN
TP_BAT_GND: HECTOR_WATCH_1_TPTP20R; HECTOR_WATCH_1_TP20R
TP_ON: HECTOR_WATCH_1_TPTP20R; HECTOR_WATCH_1_TP20R
TP_OP: HECTOR_WATCH_1_TPTP20R; HECTOR_WATCH_1_TP20R
TP_VBAT: HECTOR_WATCH_1_TPTP20R; HECTOR_WATCH_1_TP20R
U3: MAX17048G+T10; ESP32_C6_LIBRARY_SON50P200X200X80-9N

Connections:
3V3: C34.2, IC2.C2 (VDD), Q1.2 (S), R5.2, R7.2, R8.2, R_PWR_EPD.2; also elsewhere on the board
ALERT: U3.5 (!ALERT); also elsewhere on the board
D+: D3.4 (I/O2_2); also elsewhere on the board
D-: D3.6 (I/O1_2); also elsewhere on the board
DN: D3.1 (I/O1_1), J4.A7 (DN1), J4.B7 (DN2)
DP: D3.3 (I/O2_1), J4.A6 (DP1), J4.B6 (DP2)
EPD_3V3: C1-EP-DR.2, EPD_C5.2, J1.15, J1.16, L5.2, Q1.3 (D)
EPD_BUSY: J1.9; also elsewhere on the board
EPD_CS: J1.12; also elsewhere on the board
EPD_DC: J1.11; also elsewhere on the board
EPD_RST: J1.10; also elsewhere on the board
GDR: J1.2, Q3.1 (G), R2_EP_DR.2
GND: C1-EP-DR.1, C27.1, C29.1, C30.1, C31.1, C32.1, C34.1, C42.2, C43.2, D3.2 (GND), D4.1 (K), EPD_C1.1, EPD_C2.1, EPD_C5.1, EPD_C6.1, EPD_C7.1, EPD_C8.1, EPD_C9.1, EPD_C10.1, EPD_C11.1, EPD_C12.1, IC2.B1 (IN/TRIG), IC2.B3 (GND), J1.8, J1.17, J1.MP1, J1.MP2, J4.A1_B12 (GND), J4.A12_B1 (GND), J4.SH1 (SHIELD), J4.SH2 (SHIELD), J4.SH3 (SHIELD), J4.SH4 (SHIELD), R1_USB1.1, R2_EP_DR.1, R2_USB.2, R_TYPE_SEL.1, SJ1.1, SW_DN.1, SW_ENT.1, SW_UP.1, TP_BAT_GND.TP, U3.1 (CTG), U3.4 (GND), U3.6 (QSTRT), U3.9 (EP); also elsewhere on the board
HAPTIC_EN: IC2.A1 (EN); also elsewhere on the board
MOSI: J1.14; also elsewhere on the board
unnamed: C32.2, IC2.A2 (REG)
unnamed: J4.B5 (CC2), R2_USB.1
unnamed: J4.A5 (CC1), R1_USB1.2
unnamed: EPD_C2.2, J1.4
unnamed: EPD_C6.2, J1.18
unnamed: EPD_C1.2, J1.5
unnamed: EPD_C7.2, J1.19
unnamed: EPD_C8.2, J1.20
unnamed: EPD_C10.2, J1.22
unnamed: EPD_C12.2, J1.24
unnamed: C2-EP-DR.1, D5.2 (A), L5.1, Q3.3 (D)
unnamed: R1_EP_DR.1, R_TYPE_SEL.2, SJ1.2
unnamed: C2-EP-DR.2, D2.1 (K), D4.2 (A)
OUT+: IC2.A3 (OUT+), TP_OP.TP
OUT-: IC2.C3 (OUT-), TP_ON.TP
P0.13: C30.2, R5.1, SW_UP.2; also elsewhere on the board
P0.14: C31.2, R8.1, SW_ENT.2; also elsewhere on the board
P1.01: Q1.1 (G), R_PWR_EPD.1; also elsewhere on the board
P1.02: C29.2, R7.1, SW_DN.2; also elsewhere on the board
PREVGH: D5.1 (K), EPD_C9.2, J1.21
PREVGL: D2.2 (A), EPD_C11.2, J1.23
RESE: J1.3, Q3.2 (S), R1_EP_DR.2
SCK: J1.13; also elsewhere on the board
SCL: IC2.C1 (SCL), U3.7 (SCL); also elsewhere on the board
SDA: IC2.B2 (SDA), U3.8 (SDA); also elsewhere on the board
VBAT: C27.2, TP_VBAT.TP, U3.2 (CELL), U3.3 (VDD); also elsewhere on the board
VBUS: C42.1, C43.1, D3.5 (VBUS), J4.A4_B9 (VBUS), J4.A9_B4 (VBUS); also elsewhere on the board

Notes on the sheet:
Haptic Driver
Buttons
Fuel Gauge
USB C Connector & ESD Protection
E-Paper Display Connector
E-Paper Drive Circuit
DMG2305UX-7

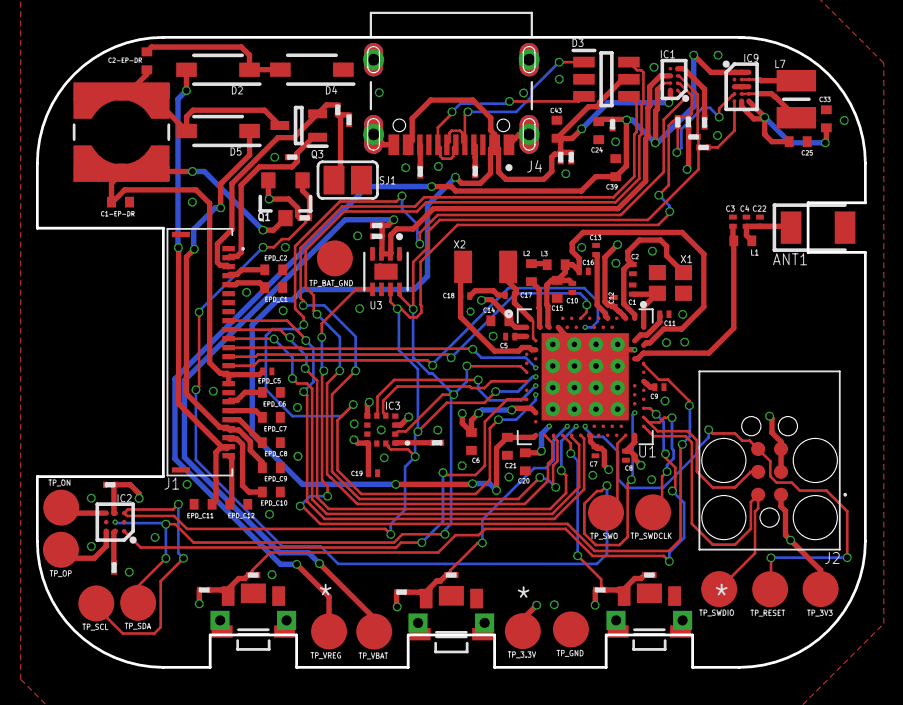
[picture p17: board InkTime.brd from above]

Board: 4 copper layers, 46.0 x 35.0 mm, 105 parts (0 on the bottom side), 70 nets.

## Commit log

2026-04-10 added Hardware and Manufacturing folders
    [InkTime.brd, InkTime.sch]
2026-04-18 Fixed issues and finished 3D Models
    [Bill_of_Materials.csv, InkTime.brd, InkTime.sch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]
2026-04-20 Updated Bill of Materials
    [Bill_of_Materials.csv]

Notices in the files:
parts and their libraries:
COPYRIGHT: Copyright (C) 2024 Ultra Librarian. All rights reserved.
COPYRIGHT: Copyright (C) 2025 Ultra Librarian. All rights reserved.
